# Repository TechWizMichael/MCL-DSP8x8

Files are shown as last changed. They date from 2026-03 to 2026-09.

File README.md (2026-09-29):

# MCL-DSP8x8
## Description
Audio Signal Processor based on ESP32-S3 and ADAU1452.

## Goals
+ Eight channels of analog audio input and output
+ Compatibility with "12V" automotive systems
+ Remote control through ESP32
+ download and upload of settings to restore after flashing new firmware

## Current State of Firmware
+ Bit of a mess. It's been changing as I've been messing with testing.
+ USB programming of ESP32 is functional.
+ ESP32 successfully programs ADAU1452 and AK4619VN.
+ Bluetooth functionality was briefly tested, with a generic BLE app on android controlling output gain.
+ Recommended to edit SigmaStudio project for own needs before programming.

## Current state of hardware
### V0.7 PCB (latest complete version)
- On paper, everything works. The ESP32-S3 may need to be flashed using UART pins for the first time, but it is otherwise functional.
- In practice, there are many issues that make it problematic for use with actual audio systems.
- View issues tab for current issues and progress/solutions

### v0.8 (In Progress)
- Goal to address many of the issues seen in v0.7.
- The primary issue is the noise in the analog signal, which is addressed by a second 3.3V rail for analog components.
- This means the main board has a maximum input and output of around +2.2dBu.
- There is also additional options for input connectors, but they must be added separately.
- The following connectors have complete v1 designs:
  - Stereo XLR
  - Stereo RCA
  - Eight-channel RCA
- Current designs for input boards passively attenuate signal -20dB, so a maximum input signal of +22dBu is acceptable.
- Maximum output is still around +2.2 dBu.
- If the maximum input signal will be under +2.2 dBu, the output boards can be used as input boards.
  - This is because they are direct connections to the main board.

#### v0.8 To-do:
- [x] New analog rail
- [x] Reset IC for ESP32
- [x] Upgrade buttons
- [x] Upgrade/Replace audio connectors
- [x] swap I2S connections for AK4619VN
- [x] \(optional) Ability to power from USB 5V rail
- [x] Update output gain stage
- [x] Add Schottky diode(s) for power input
- [x] Upgrade capacitors on input
- [x] add capacitors on power rails of opamps
- [x] ESP32 controls PDN of AK4619VN
- [x] Updated layout of main board
- [x] Connector boards
- [ ] Validation of assembled design

### Preview of v0.8 from JLCPCB


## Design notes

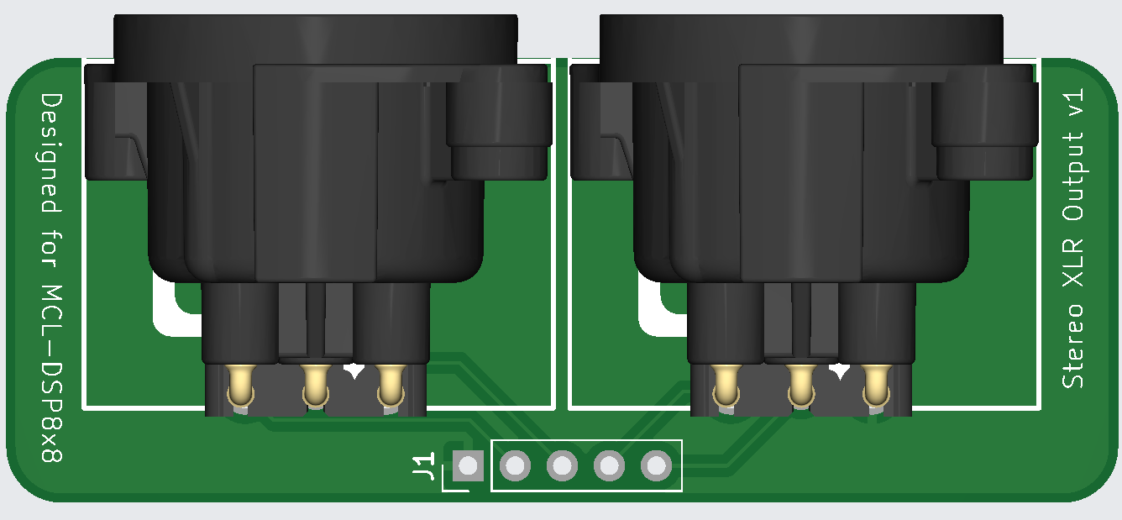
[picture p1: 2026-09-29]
PCB/MCL-DSP8x8_OUTPUT_XLR/production/Stereo XLR Output V1.png

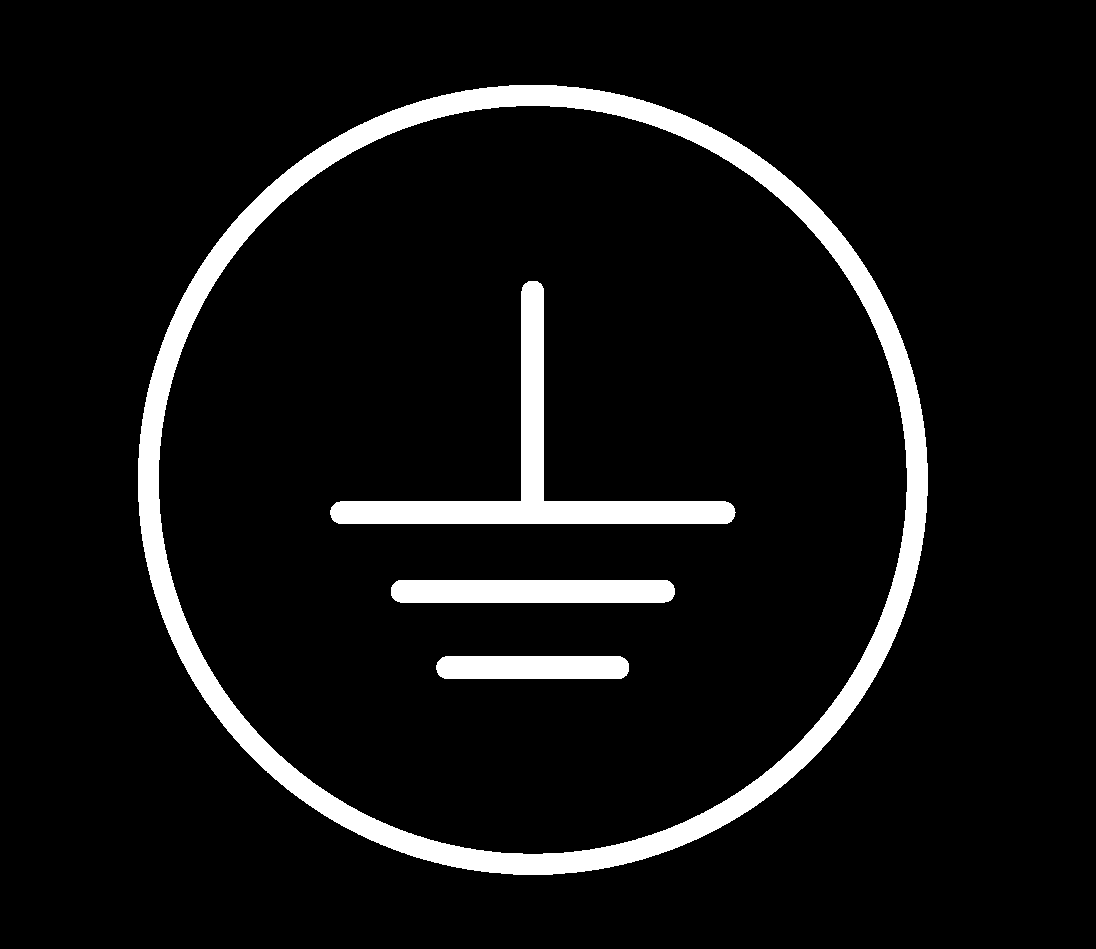
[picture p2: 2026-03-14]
PCB/DIYDSPv0.6/Silkscreen Ground Symbol.png

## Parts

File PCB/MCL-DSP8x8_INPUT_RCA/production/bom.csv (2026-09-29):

Designator | Footprint | Quantity | Value | LCSC Part #
CN1 | XDJK-0271-1650 | 1 | ~ | C7527522
R1, R3 | 0805 | 2 | 82k | C22356755
R2, R4, R6, R8 | 0805 | 4 | 10k | C3152175

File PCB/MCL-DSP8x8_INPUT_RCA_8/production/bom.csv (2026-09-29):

Designator | Footprint | Quantity | Value | LCSC Part #
CN1, CN2, CN3, CN4 | XDJK-0271-1650 | 4 | ~ | C7527522
R1, R13, R15, R17, R19, R3, R5, R7 | 0805 | 8 | 82k | C22356755
R10, R11, R12, R14, R16, R18, R2, R20, R21, R22, R23, R24, R4, R6, R8, R9 | 0805 | 16 | 10k | C3152175

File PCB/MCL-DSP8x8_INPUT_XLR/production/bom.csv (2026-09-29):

Designator | Footprint | Quantity | Value | LCSC Part #
PS1, PS2 | NC3FAAH1 | 2 | ~ | C368464
R1, R3, R5, R7 | 0805 | 4 | 82k | C22356755
R2, R4, R6, R8 | 0805 | 4 | 10k | C3152175

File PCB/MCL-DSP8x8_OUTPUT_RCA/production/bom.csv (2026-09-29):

Designator | Footprint | Quantity | Value | LCSC Part #
CN1 | XDJK-0271-1650 | 1 | ~ | C7527522
R6, R8 | 0805 | 2 | 10k | C3152175

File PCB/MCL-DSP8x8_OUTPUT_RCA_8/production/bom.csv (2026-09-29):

Designator | Footprint | Quantity | Value | LCSC Part #
CN1, CN2, CN3, CN4 | XDJK-0271-1650 | 4 | ~ | C7527522
R1, R2, R3, R4, R5, R6, R7, R8 | 0805 | 8 | 10k | C3152175

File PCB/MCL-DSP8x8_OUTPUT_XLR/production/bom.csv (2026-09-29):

Designator | Footprint | Quantity | Value | LCSC Part #
PS1 | NC3MAAH-0 | 1 | ~ | C368531
PS2 | NC3MAAH-0 | 1 | ~

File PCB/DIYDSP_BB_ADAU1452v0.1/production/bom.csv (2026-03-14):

Designator | Footprint | Quantity | Value | LCSC Part #
C1, C10, C11, C13, C17, C18, C21, C30, C32, C5, C7, C9 | 0805 | 12 | 100n | C28233
C12, C14, C16, C20 | 0805 | 4 | 10n | C1710
C15, C19, C22, C23 | 0805 | 4 | 1u | C28323
C2, C31, C33, C6, C8 | 0805 | 5 | 10u | C15850
C24, C25 | 0805 | 2 | 22p | C1804
C26 | 0805 | 1 | 4.7n | C1744
C27 | 0805 | 1 | 47p | C14857
C3 | 0805 | 1 | 1n | C46653
C4 | 0805 | 1 | 100p | C1790
D1 | 0805 | 1 | LED | C84256
R1, R5 | 0805 | 2 | 2.2k | C17520
R2, R3 | 0805 | 2 | 100 | C17408
R4 | 0805 | 1 | 1k | C17513
U1 | ADAU1452WBCPZ-RL | 1 | ADAU1452 | C462188
U2 | AMS1117-1.2 | 1 | AMS1117-1.2 | C2992568
Y1 | Crystal_SMD_5032-2Pin_5.0x3.2mm | 1 | 12.288M | C20624119

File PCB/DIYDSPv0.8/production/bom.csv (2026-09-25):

Designator | Footprint | Quantity | Value | LCSC Part #
C1, C101, C102, C108, C109, C112, C113, C13, C18, C20, C21, C25, C26, C28, C3, C42, C44, C58, C59, C64, C65, C76, C77, C84, C85, C96, C97 | 0603 | 27 | 10u | C96446
C10, C2, C4, C9 | 0402 | 4 | 2.2u | C12530
C100, C107, C68, C83 | RVT1V221M0810 | 4 | 220uF | C18221522
C103, C104, C110, C111, C50, C61, C78, C95 | 0805 | 8 | 22u | C45783
C105, C106, C11, C114, C115, C116, C12, C14, C15, C19, C22, C23, C24, C27, C33, C36, C38, C39, C40, C41, C47, C48, C49, C5, C51, C52, C53, C6, C60, C62, C63, C66, C67, C73, C74, C75, C86, C87, C88, C89, C94, C98, C99 | 0402 | 43 | 100n | C307331
C16, C17, C34, C35 | 0402 | 4 | 10n | C15195
C29 | 0402 | 1 | 4.7n | C1538
C30, C31, C45, C46, C54, C55, C56, C57, C69, C70, C71, C72, C79, C80, C81, C82, C90, C91, C92, C93 | 0402 | 20 | 1u | C52923
C32 | 0402 | 1 | 1n | C1523
C37 | 0402 | 1 | 100p | C1546
C43 | 0402 | 1 | 47p | C1567
C7, C8 | 0402 | 2 | 22p | C1555
CN1 | MX126-5.0-02P-GN01-Cu-S-A | 1 | ~ | C5188434
D1, D2, D7, D8 | 0805 | 4 | LED | C84256
D3, D4, D5 | CUS08F30,H3F | 3 | ~ | C150183
D6 | SMF20CA | 1 | ~ | C42371747
R1, R10, R11, R14, R19, R2, R20, R25, R3, R4, R5, R6, R7, R74, R8, R81, R9 | 0805 | 17 | 100 | C17408
R12, R13, R21, R26, R27 | 0402 | 5 | 10k | C25744
R15, R18, R28, R29, R44, R45, R56, R57, R70, R71 | 0402 | 10 | 1k | C11702
R16, R17 | 0402 | 2 | 2.2k | C25879
R22, R30, R31, R32, R33, R34, R35, R36, R37, R38, R39, R40, R41, R42, R43, R46, R47, R48, R49, R50, R51, R52, R53, R54, R55, R58, R59, R60, R61, R62, R63, R64, R65, R66, R67, R68, R69, R72, R73, R75, R76, R77, R78, R79, R80 | 0402 | 45 | 100k | C25741
R23, R24 | 0402 | 2 | 5.1k | C25905
SW1, SW2, SW3 | TS110916043 | 3 | ~ | C22375348
U1 | ADAU1452WBCPZ-RL | 1 | ADAU1452 | C462188
U10, U11, U12, U13, U14, U15, U16, U17, U18, U19, U20, U21, U22, U24, U25, U8, U9 | TLV9062IDR | 17 | ~ | C398355
U2, U3 | AK4619VN | 2 | ~ | C3034747
U23, U26 | K7803-1000_C50396471 | 2 | ~
U4 | AMS1117-1.2 | 1 | AMS1117-1.2 | C2992568
U5 | ESP32-S3-WROOM-1U-N8 | 1 | ~ | C3013946
U6 | ADM811TARTZ-REEL7 | 1 | ~ | C462205
U7 | GT-USB-7010ASV | 1 | ~ | C2988369
X1 | S47SMD12.288M20PF20R30B3 | 1 | 12.288MHz | C5346044

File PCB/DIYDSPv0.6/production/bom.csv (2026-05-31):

Designator | Footprint | Quantity | Value | LCSC Part #
C1, C14, C19, C24, C25, C27, C3, C31, C32, C34, C51 | 0603 | 11 | 10u | C96446
C10, C11, C12, C55, C7 | 0805 | 5 | 22u | C45783
C13, C17, C18, C20, C21, C26, C28, C29, C30, C33, C39, C43, C44, C45, C46, C48, C5, C52, C53, C54, C56, C57, C6 | 0402 | 23 | 100n | C307331
C15, C16, C2, C4 | 0402 | 4 | 2.2u | C12530
C22, C23, C40, C41 | 0402 | 4 | 10n | C15195
C35 | 0402 | 1 | 4.7n | C1538
C36, C37, C49, C50, C58, C59, C60, C61, C62, C63, C64, C65, C66, C67, C68, C69, C70, C71, C72, C73, C74, C75, C76, C77, C78, C79, C80, C81, C82, C83, C84, C85, C86, C87, C88, C89 | 0402 | 36 | 1u | C52923
C38 | 0402 | 1 | 1n | C1523
C42 | 0402 | 1 | 100p | C1546
C47 | 0402 | 1 | 47p | C1567
C8, C9 | 0402 | 2 | 22p | C1555
CN1 | MX126-5.0-02P-GN01-Cu-S-A | 1 | ~ | C5188434
D1 | SMF20CA | 1 | ~ | C42371747
D2, D3, D4 | 0805 | 3 | LED | C84256
R1, R10, R11, R17, R18, R19, R2, R23, R24, R3, R4, R5, R6, R7, R8, R9 | 0805 | 16 | 100 | C17408
R12, R13, R25, R26, R27, R76 | 0402 | 6 | 10k | C25744
R14, R36, R37, R38, R39, R40, R41, R42, R43, R44, R45, R46, R47, R48, R49, R50, R51, R60, R61, R62, R63, R64, R65, R66, R67, R68, R69, R70, R71, R72, R73, R74, R75 | 0402 | 33 | 100k | C25741
R15, R16 | 0402 | 2 | 2.2k | C25879
R20 | 0402 | 1 | 1k | C11702
R21, R22 | 0402 | 2 | 5.1k | C25905
R28, R29, R30, R31, R32, R33, R34, R35, R52, R53, R54, R55, R56, R57, R58, R59 | 0603 | 16 | 220k | C22961
U1 | ADAU1452WBCPZ-RL | 1 | ADAU1452 | C462188
U10 | GT-USB-7010ASV | 1 | ~ | C2988369
U11, U12, U13, U14, U15, U16, U8, U9 | PJ-320D | 8 | ~ | C22459515
U17 | ESP32-S3-WROOM-1U-N8 | 1 | ~ | C3013946
U18, U19, U7 | YTS1C0033BBG01 | 3 | ~ | C5188566
U2, U3 | AK4619VN | 2 | ~ | C3034747
U20, U21, U22, U23 | LM324DT | 4 | ~ | C71035
U4 | K7803M-1000R3 | 1 | ~ | C22749779
U5 | AMS1117-1.2 | 1 | AMS1117-1.2 | C2992568
U6 | ADM811TARTZ-REEL7 | 1 | ~ | C462205
X1 | S47SMD12.288M20PF20R30B3 | 1 | 12.288MHz | C5346044

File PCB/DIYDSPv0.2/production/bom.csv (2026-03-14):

Designator | Footprint | Quantity | Value | LCSC Part #
C1, C15, C2, C27, C28, C29, C48, C5, C52, C53, C54, C55, C56, C57, C58, C59, C6, C8, C9 | 0805 | 19 | 10u | C15850
C10, C11, C33, C50, C7 | 0805 | 5 | 22u | C45783
C12, C13, C14, C16, C17, C18, C19, C20, C21, C24, C25, C26, C37, C41, C42, C43, C44, C49, C51 | 0603 | 19 | 100n | C14663
C22, C23, C38, C39 | 0402 | 4 | 10n | C15195
C3, C4 | 0402 | 2 | 22p | C1555
C30 | 0402 | 1 | 4.7n | C1538
C31, C32, C46, C47, C60, C61, C62, C63, C64, C65, C66, C67, C68, C69, C70, C71, C72, C73, C74, C75, C76, C77, C78, C79, C80, C81, C82, C83, C84, C85, C86, C87, C88, C89, C90, C91 | 0402 | 36 | 1u | C52923
C34 | 0402 | 1 | 1n | C1523
C35, C36 | 0805 | 2 | 2.2u | C377773
C40 | 0402 | 1 | 100p | C1546
C45 | 0402 | 1 | 47p | C1567
D1 | SMF20CA | 1 | ~ | C42371747
D2, D3, D4 | 0805 | 3 | LED | C84256
R1, R4, R5, R6 | 1206 | 4 | 100 | C17901
R10, R100, R101, R102, R103, R104, R105, R106, R107, R108, R109, R11, R110, R111, R112, R113, R114, R115, R12, R13, R14, R15, R20, R21, R22, R23, R24, R25, R26, R27, R32, R33, R34, R35, R44, R45, R46, R47, R48, R49, R50, R51, R52, R53, R54, R55, R56, R57, R58, R59, R60, R61, R62, R63, R64, R65, R66, R67, R68, R69, R70, R71, R72, R73, R74, R75, R84, R85, R86, R87, R88, R89, R90, R91, R92, R93, R94, R95, R96, R97, R98, R99 | 1206 | 82 | 10k | C17902
R16, R17, R18, R19, R28, R29, R30, R31, R36, R37, R38, R39, R40, R41, R42, R43, R76, R77, R78, R79, R80, R81, R82, R83 | 0805 | 24 | 22k | C17560
R2, R3 | 0603 | 2 | 2.2k | C4190
R7, R8 | 0603 | 2 | 5.1k | C23186
R9 | 0402 | 1 | 1k | C11702
U1, U5 | AK4619VN | 2 | ~ | C3034747
U10, U12, U13, U14, U15, U16, U17, U18, U19, U7, U8, U9 | TS912IDT | 12 | ~ | C73655
U11 | ESP32-S3-WROOM-1 | 1 | ~
U2 | ADAU1452WBCPZ-RL | 1 | ADAU1452 | C462188
U3 | K7803M-1000R3 | 1 | ~ | C22749779
U4 | AMS1117-1.2 | 1 | AMS1117-1.2 | C2992568
U6 | GT-USB-7010ASV | 1 | ~ | C2988369
Y1 | Crystal_SMD_5032-2Pin_5.0x3.2mm | 1 | 12.288M | C20624119

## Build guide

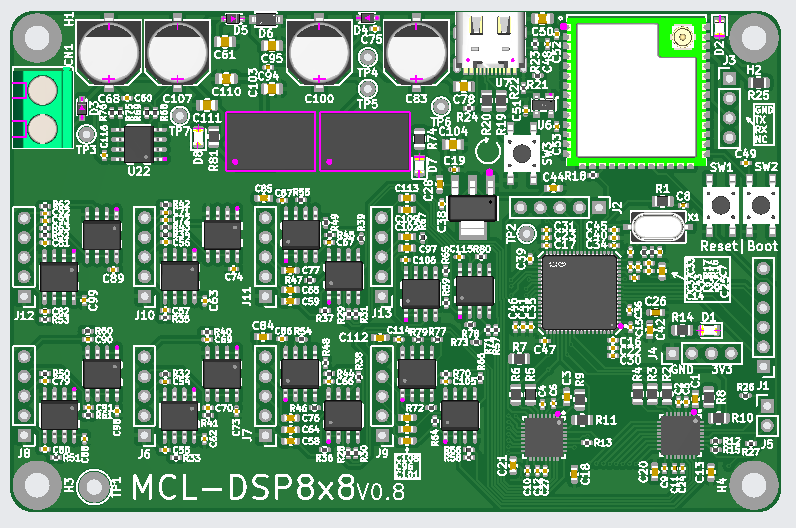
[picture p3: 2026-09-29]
PCB/DIYDSPv0.8/production/MCL-DSP8x8v0.8 Assembled Preview.png

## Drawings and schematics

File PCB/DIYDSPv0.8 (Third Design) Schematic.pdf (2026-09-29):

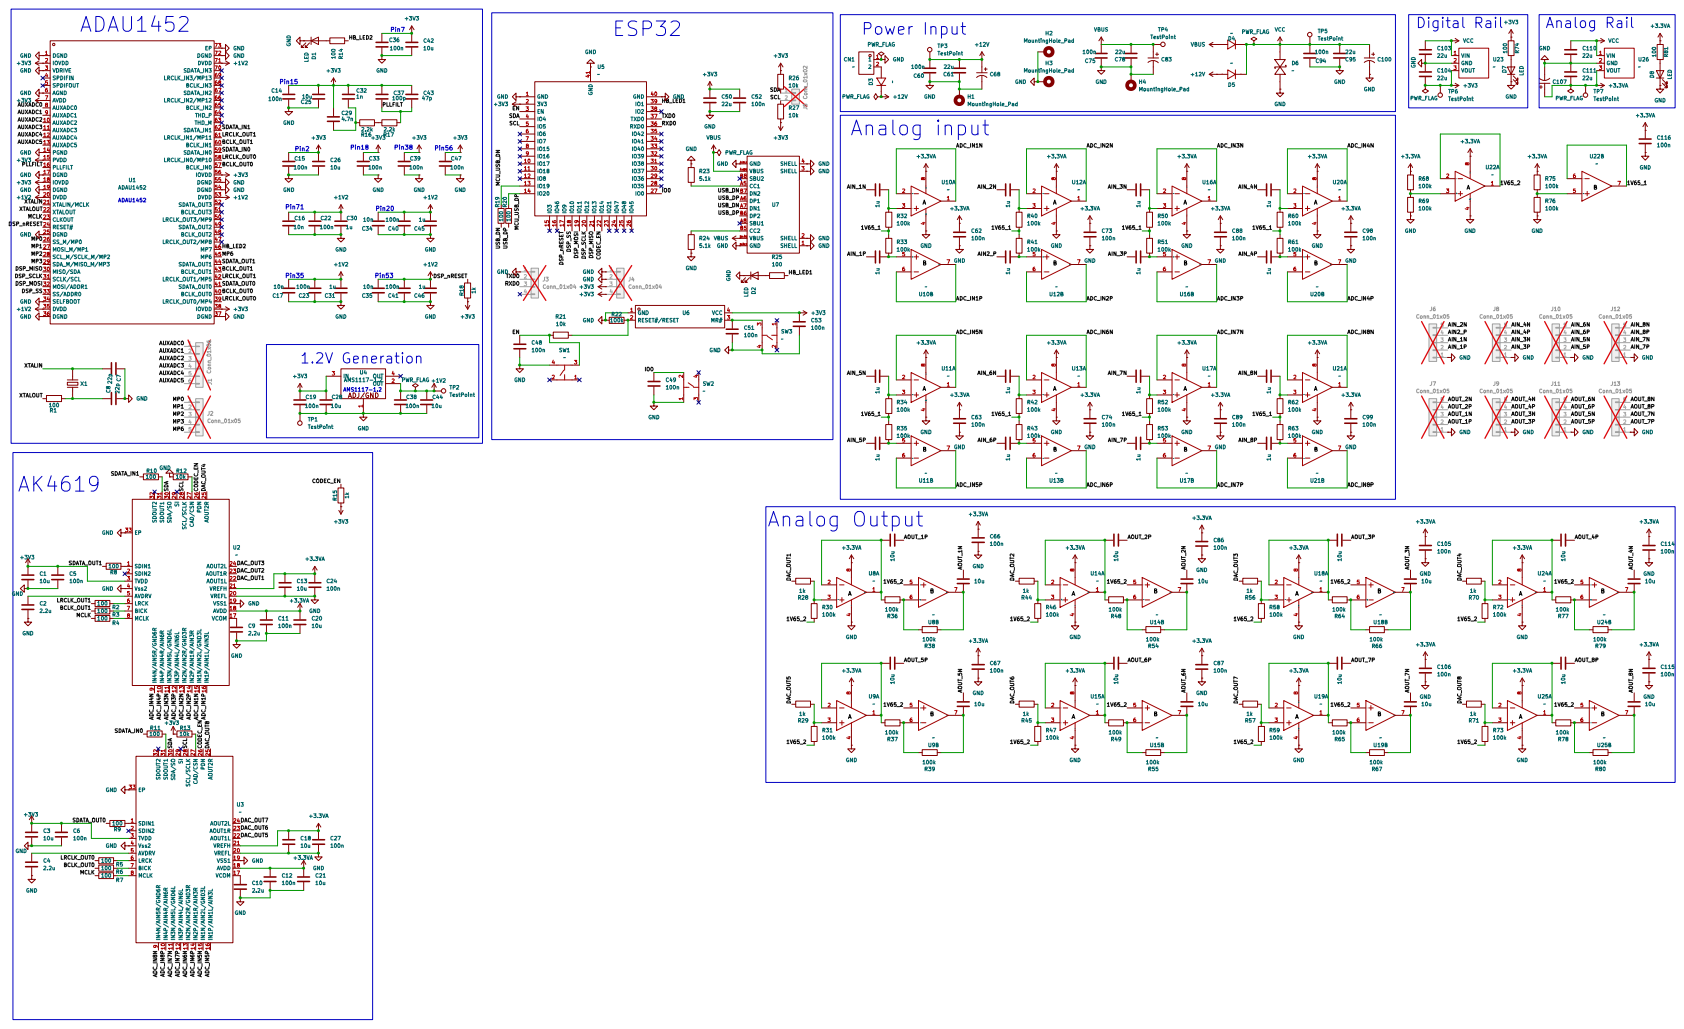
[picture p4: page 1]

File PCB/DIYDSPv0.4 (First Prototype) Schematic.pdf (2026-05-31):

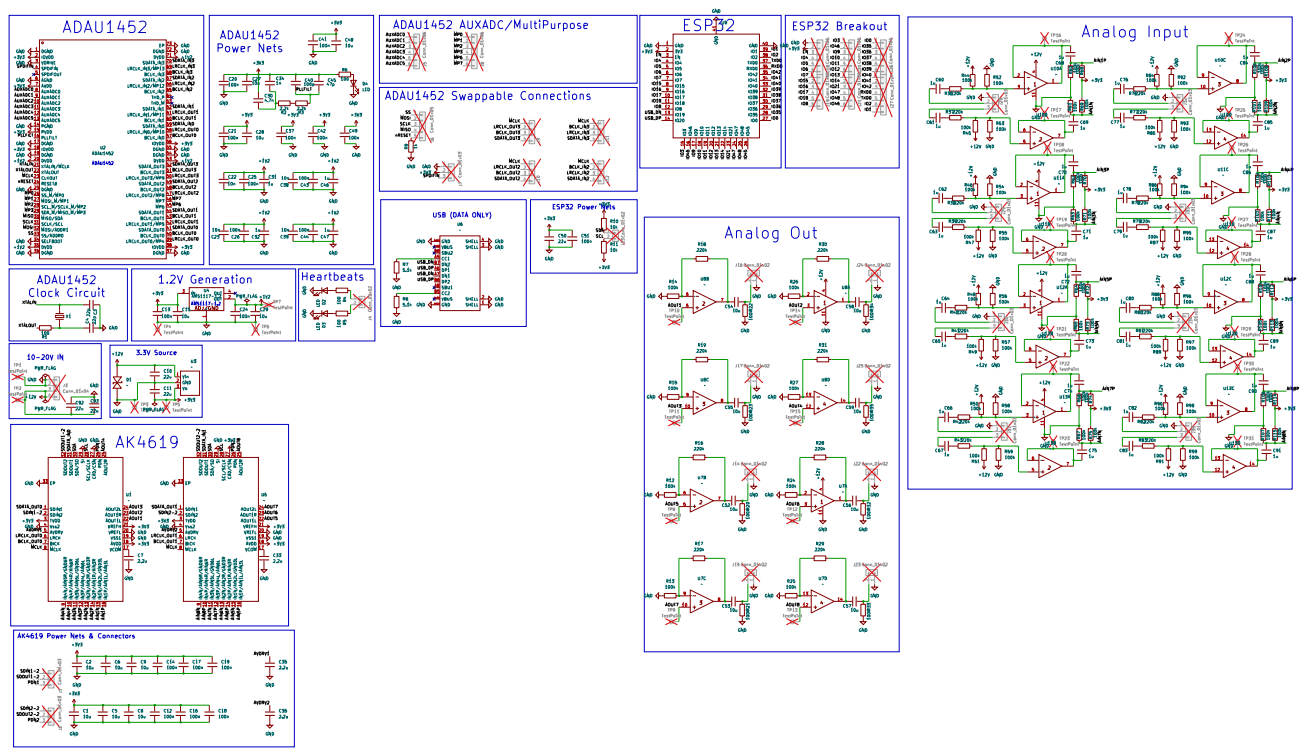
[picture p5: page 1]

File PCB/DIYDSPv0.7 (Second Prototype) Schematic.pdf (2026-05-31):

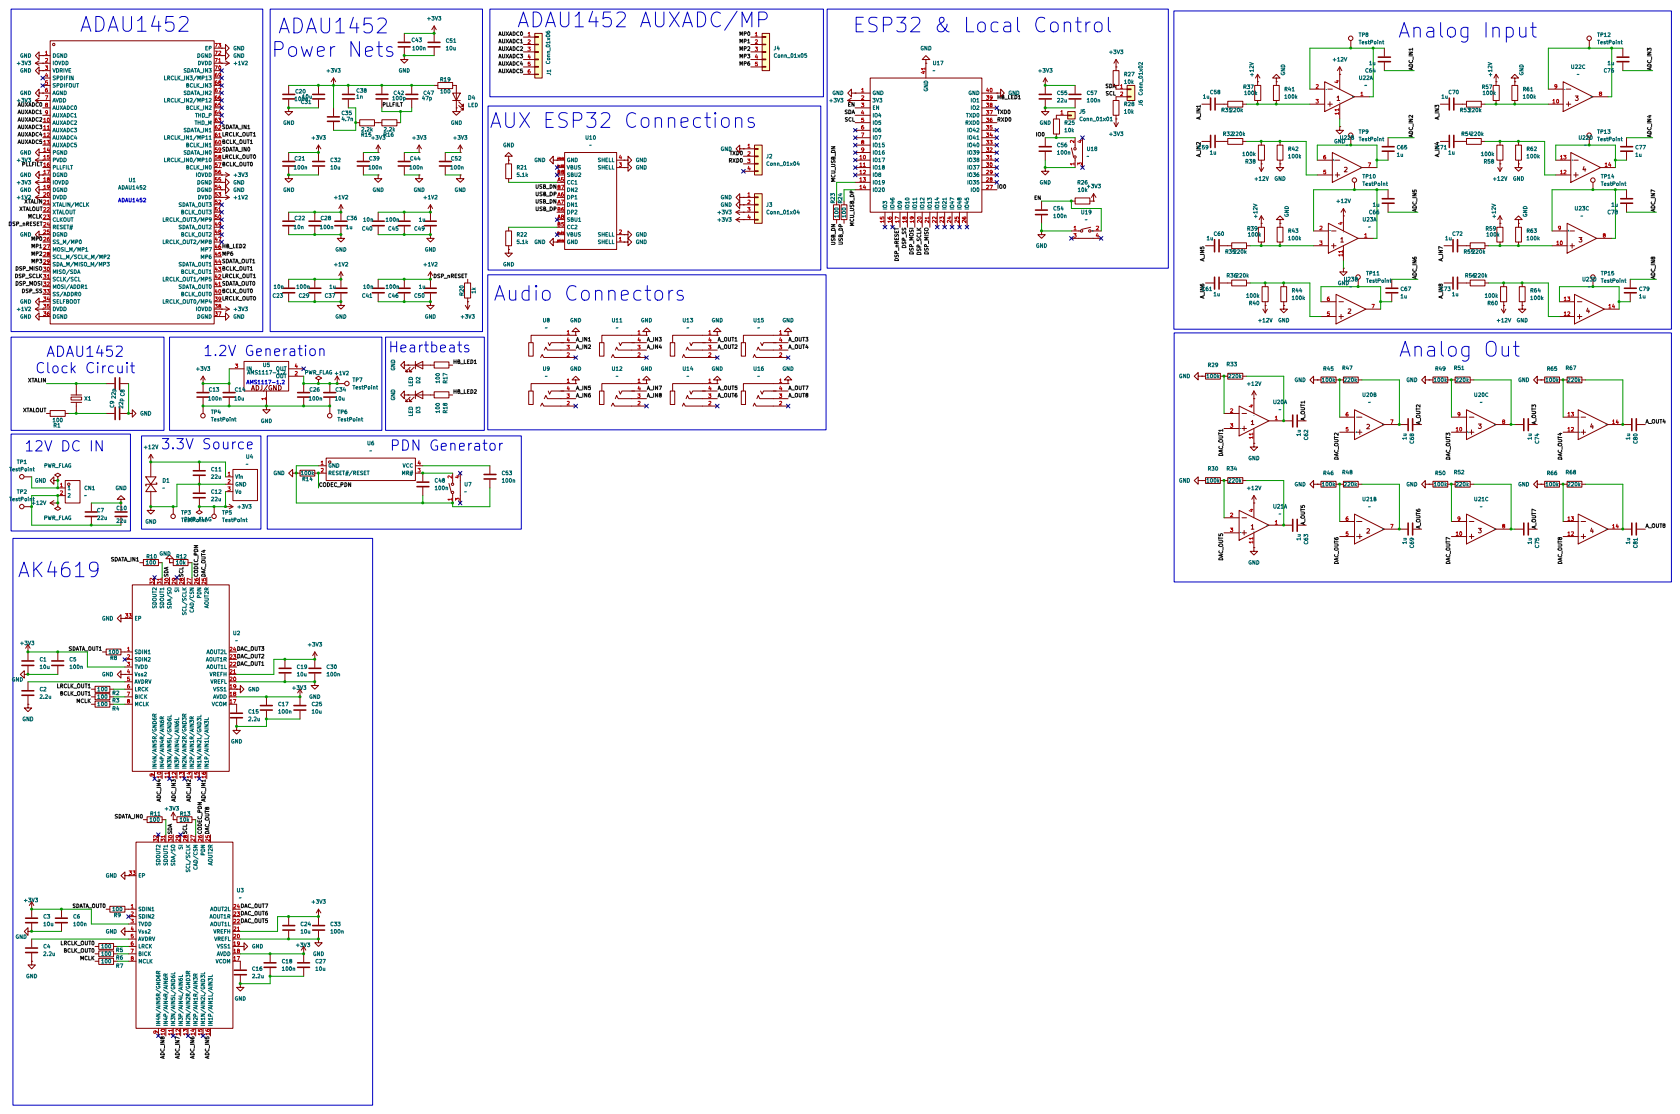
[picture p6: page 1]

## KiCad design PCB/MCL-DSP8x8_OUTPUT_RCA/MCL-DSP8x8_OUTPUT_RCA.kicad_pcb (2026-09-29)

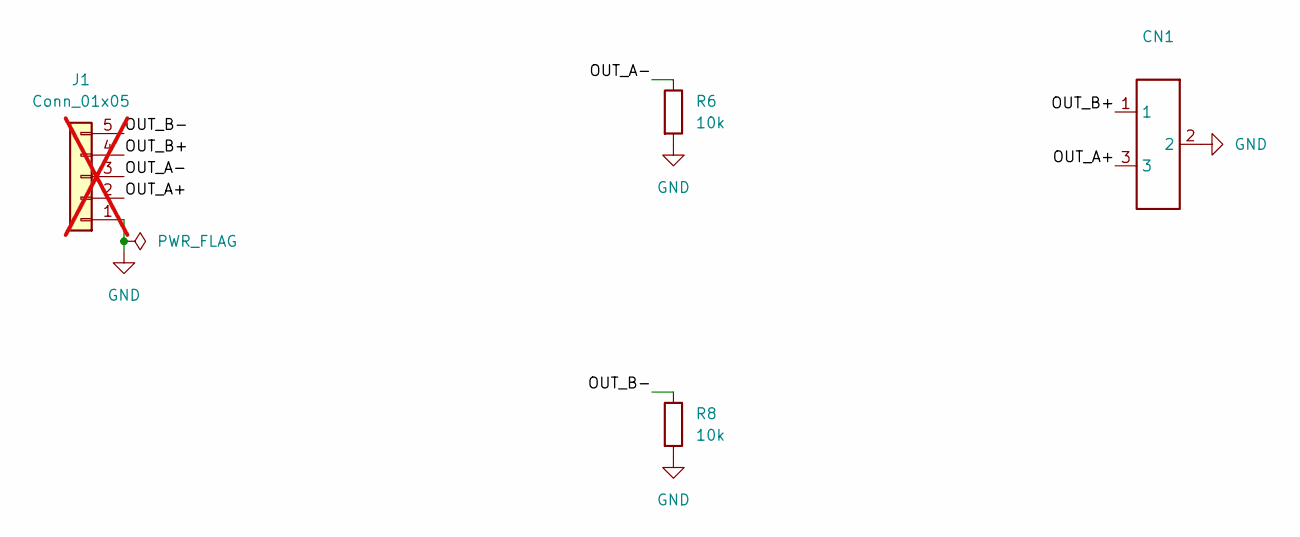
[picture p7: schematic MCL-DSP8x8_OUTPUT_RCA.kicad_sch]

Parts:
CN1: XDJK-0271-1650; Manufacturer Part XDJK-0271-1650; LCSC Part Name 双层莲花座
J1: Conn_01x05; PinHeader_1x05_P2.54mm_Vertical; not fitted
R6, R8: 10k; R_0805_2012Metric_Pad1.20x1.40mm_HandSolder; LCSC Part # C3152175

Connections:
/OUT_A+: CN1.3, J1.2
/OUT_A-: J1.3, R6.1
/OUT_B+: CN1.1, J1.4
/OUT_B-: J1.5, R8.1
GND: CN1.2, J1.1, R6.2, R8.2

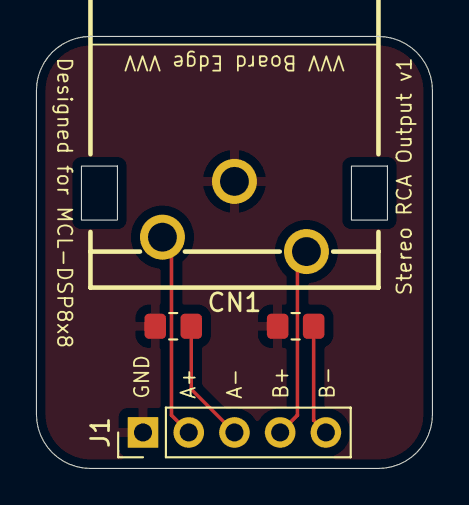
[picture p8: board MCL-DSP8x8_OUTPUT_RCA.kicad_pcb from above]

Board: 2 copper layers, 22.0 x 24.0 mm, 4 parts (0 on the bottom side), 5 nets.

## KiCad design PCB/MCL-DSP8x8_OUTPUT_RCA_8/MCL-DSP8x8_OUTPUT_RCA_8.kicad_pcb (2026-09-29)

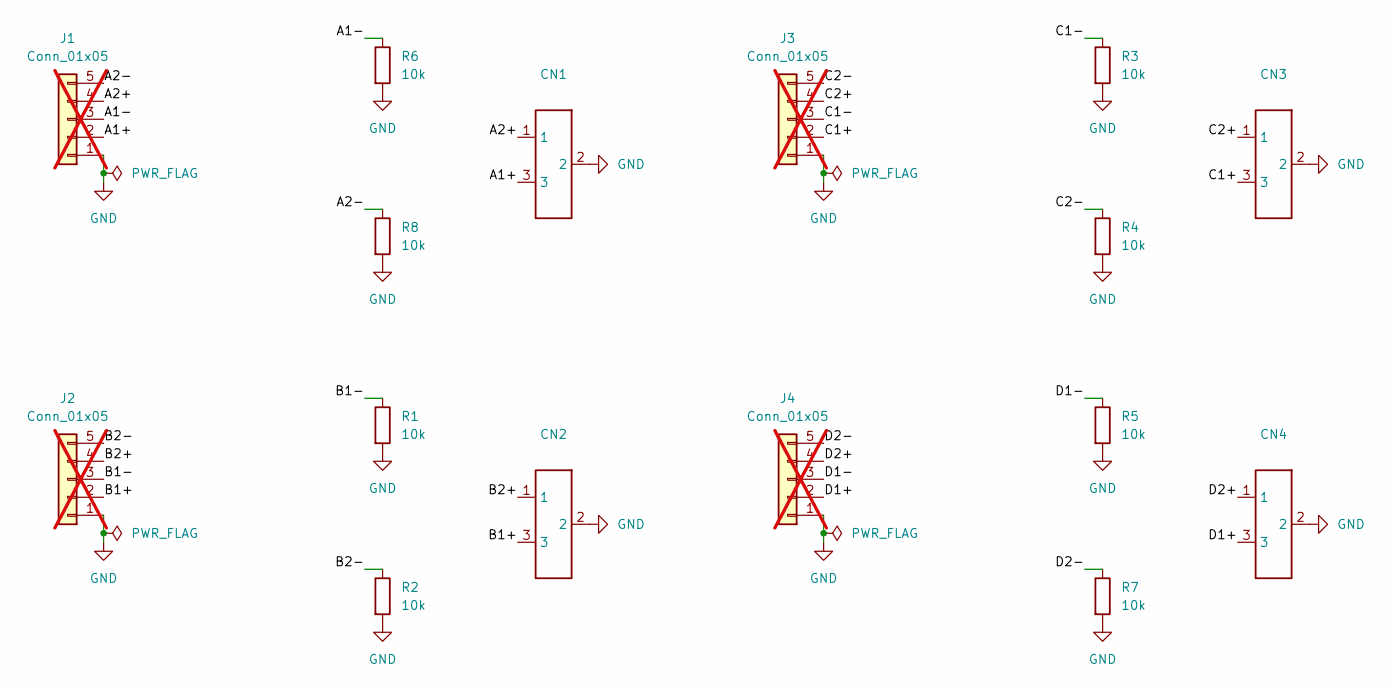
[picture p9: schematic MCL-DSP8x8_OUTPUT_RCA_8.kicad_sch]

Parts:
CN1, CN2, CN3, CN4: XDJK-0271-1650; Manufacturer Part XDJK-0271-1650; LCSC Part Name 双层莲花座
J1, J2, J3, J4: Conn_01x05; PinHeader_1x05_P2.54mm_Vertical; not fitted
R1, R2, R3, R4, R5, R6, R7, R8: 10k; R_0805_2012Metric_Pad1.20x1.40mm_HandSolder; LCSC Part # C3152175

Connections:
/A1+: CN1.3, J1.2
/A1-: J1.3, R6.1
/A2+: CN1.1, J1.4
/A2-: J1.5, R8.1
/B1+: CN2.3, J2.2
/B1-: J2.3, R1.1
/B2+: CN2.1, J2.4
/B2-: J2.5, R2.1
/C1+: CN3.3, J3.2
/C1-: J3.3, R3.1
/C2+: CN3.1, J3.4
/C2-: J3.5, R4.1
/D1+: CN4.3, J4.2
/D1-: J4.3, R5.1
/D2+: CN4.1, J4.4
/D2-: J4.5, R7.1
GND: CN1.2, CN2.2, CN3.2, CN4.2, J1.1, J2.1, J3.1, J4.1, R1.2, R2.2, R3.2, R4.2, R5.2, R6.2, R7.2, R8.2

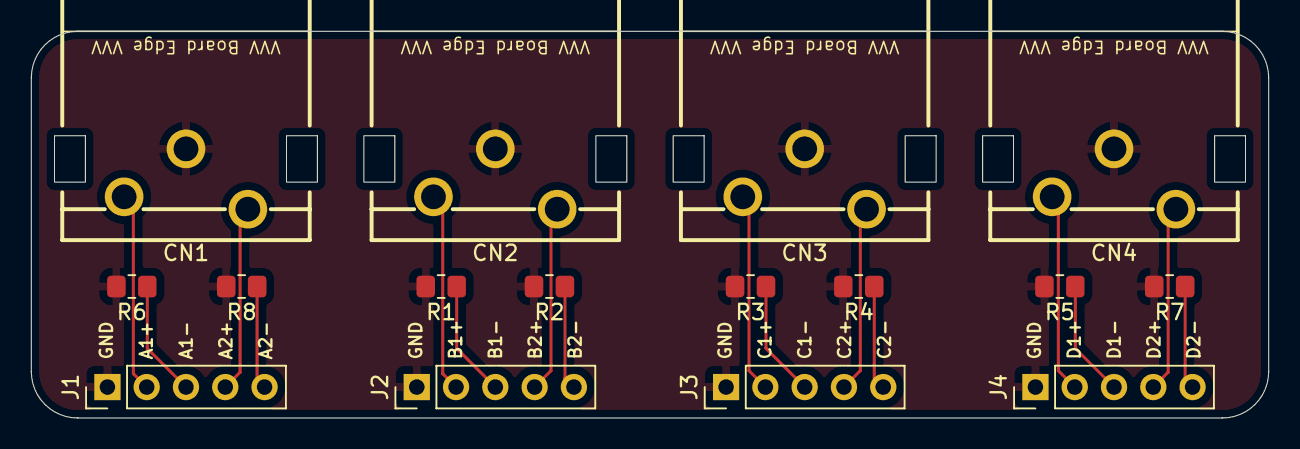
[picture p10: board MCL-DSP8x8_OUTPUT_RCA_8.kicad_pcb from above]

Board: 2 copper layers, 80.0 x 25.0 mm, 16 parts (0 on the bottom side), 17 nets.

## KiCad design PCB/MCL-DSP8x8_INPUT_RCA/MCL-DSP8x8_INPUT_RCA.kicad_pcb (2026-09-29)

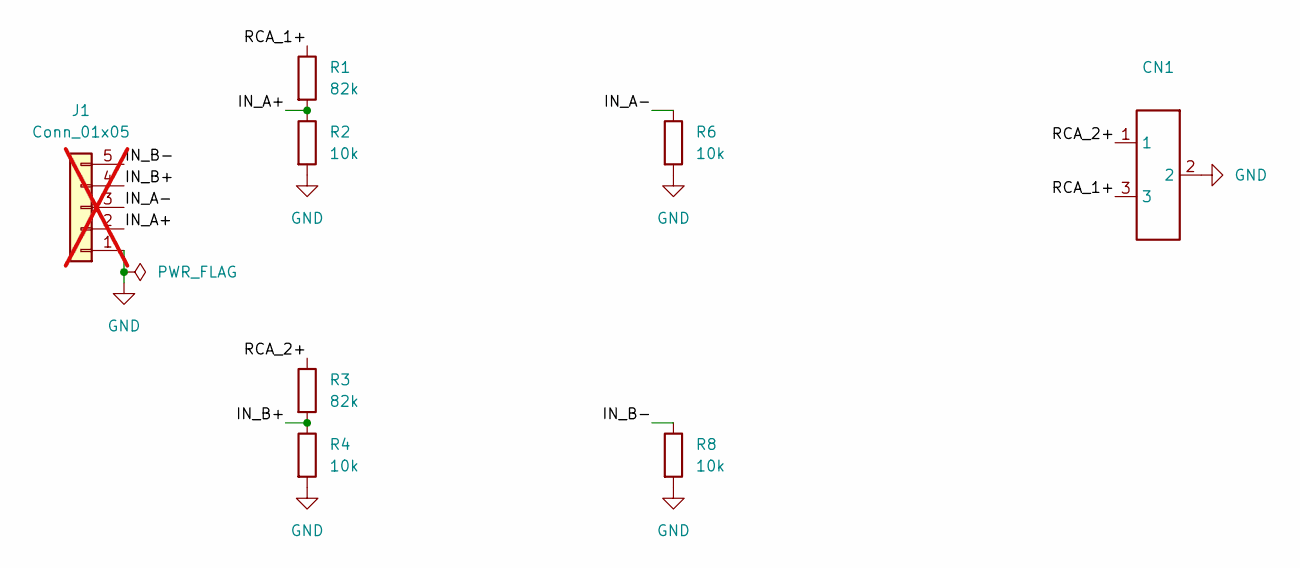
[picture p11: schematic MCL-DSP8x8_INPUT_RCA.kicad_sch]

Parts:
CN1: XDJK-0271-1650; Manufacturer Part XDJK-0271-1650; LCSC Part Name 双层莲花座
J1: Conn_01x05; PinHeader_1x05_P2.54mm_Vertical; not fitted
R1, R3: 82k; R_0805_2012Metric_Pad1.20x1.40mm_HandSolder; LCSC Part # C22356755
R2, R4, R6, R8: 10k; R_0805_2012Metric_Pad1.20x1.40mm_HandSolder; LCSC Part # C3152175

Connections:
/IN_A+: J1.2, R1.2, R2.1
/IN_A-: J1.3, R6.1
/IN_B+: J1.4, R3.2, R4.1
/IN_B-: J1.5, R8.1
/RCA_1+: CN1.3, R1.1
/RCA_2+: CN1.1, R3.1
GND: CN1.2, J1.1, R2.2, R4.2, R6.2, R8.2

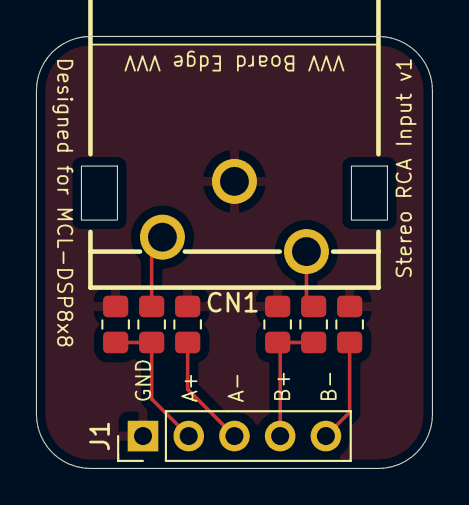
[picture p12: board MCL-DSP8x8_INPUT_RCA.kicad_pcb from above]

Board: 2 copper layers, 22.0 x 24.0 mm, 8 parts (0 on the bottom side), 7 nets.

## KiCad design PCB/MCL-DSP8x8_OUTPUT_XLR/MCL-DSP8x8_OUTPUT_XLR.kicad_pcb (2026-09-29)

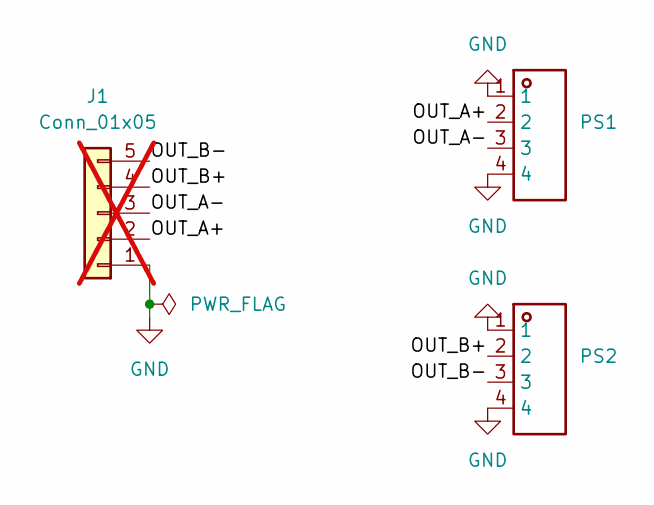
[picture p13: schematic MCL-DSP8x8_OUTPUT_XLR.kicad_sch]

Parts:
J1: Conn_01x05; PinHeader_1x05_P2.54mm_Vertical; not fitted
PS1, PS2: NC3MAAH-0; Manufacturer Part NC3MAAH-0; LCSC Part Name NC3MAAH-0

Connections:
/OUT_A+: J1.2, PS1.2
/OUT_A-: J1.3, PS1.3
/OUT_B+: J1.4, PS2.2
/OUT_B-: J1.5, PS2.3
GND: J1.1, PS1.1, PS1.4, PS2.1, PS2.4

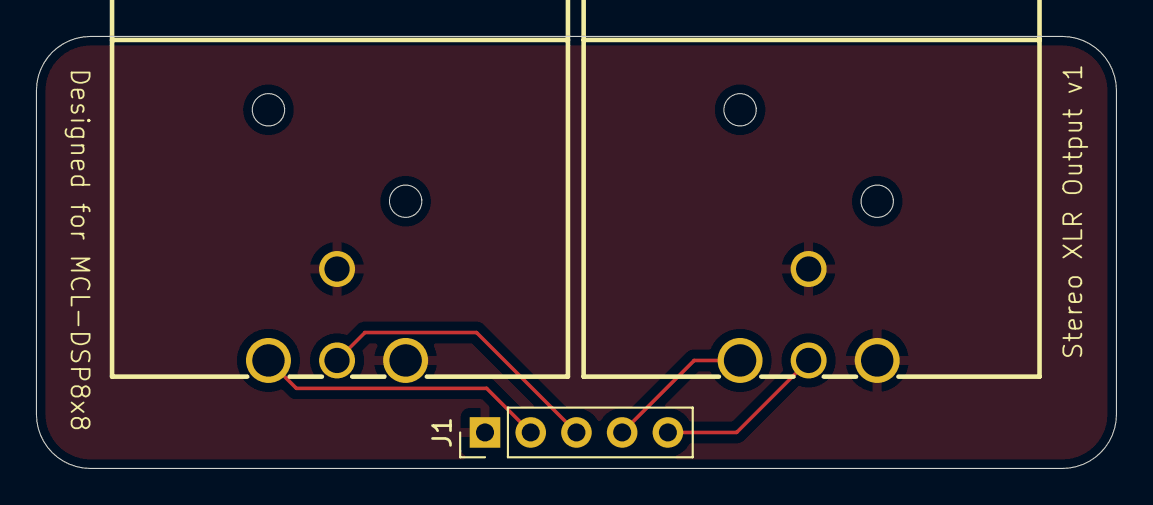
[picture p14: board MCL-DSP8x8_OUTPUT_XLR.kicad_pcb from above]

Board: 2 copper layers, 60.0 x 24.0 mm, 3 parts (0 on the bottom side), 5 nets.

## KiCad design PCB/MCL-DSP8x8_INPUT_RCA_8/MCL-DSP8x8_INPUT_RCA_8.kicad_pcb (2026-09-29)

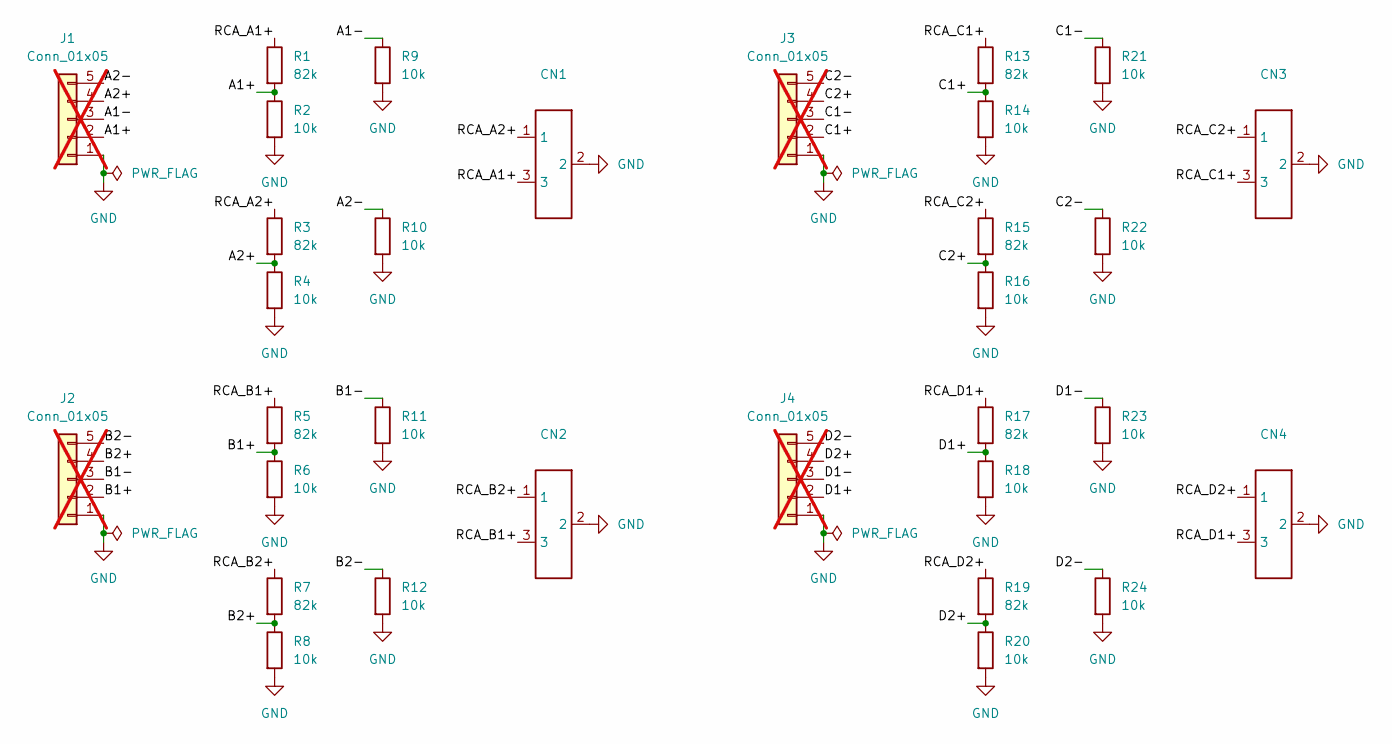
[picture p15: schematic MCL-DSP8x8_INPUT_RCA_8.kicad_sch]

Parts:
CN1, CN2, CN3, CN4: XDJK-0271-1650; Manufacturer Part XDJK-0271-1650; LCSC Part Name 双层莲花座
J1, J2, J3, J4: Conn_01x05; PinHeader_1x05_P2.54mm_Vertical; not fitted
R1, R3, R5, R7, R13, R15, R17, R19: 82k; R_0805_2012Metric_Pad1.20x1.40mm_HandSolder; LCSC Part # C22356755
R2, R4, R6, R8, R9, R10, R11, R12, R14, R16, R18, R20, R21, R22, R23, R24: 10k; R_0805_2012Metric_Pad1.20x1.40mm_HandSolder; LCSC Part # C3152175

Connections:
/A1+: J1.2, R1.2, R2.1
/A1-: J1.3, R9.1
/A2+: J1.4, R3.2, R4.1
/A2-: J1.5, R10.1
/B1+: J2.2, R5.2, R6.1
/B1-: J2.3, R11.1
/B2+: J2.4, R7.2, R8.1
/B2-: J2.5, R12.1
/C1+: J3.2, R13.2, R14.1
/C1-: J3.3, R21.1
/C2+: J3.4, R15.2, R16.1
/C2-: J3.5, R22.1
/D1+: J4.2, R17.2, R18.1
/D1-: J4.3, R23.1
/D2+: J4.4, R19.2, R20.1
/D2-: J4.5, R24.1
/RCA_A1+: CN1.3, R1.1
/RCA_A2+: CN1.1, R3.1
/RCA_B1+: CN2.3, R5.1
/RCA_B2+: CN2.1, R7.1
/RCA_C1+: CN3.3, R13.1
/RCA_C2+: CN3.1, R15.1
/RCA_D1+: CN4.3, R17.1
/RCA_D2+: CN4.1, R19.1
GND: CN1.2, CN2.2, CN3.2, CN4.2, J1.1, J2.1, J3.1, J4.1, R2.2, R4.2, R6.2, R8.2, R9.2, R10.2, R11.2, R12.2, R14.2, R16.2, R18.2, R20.2, R21.2, R22.2, R23.2, R24.2

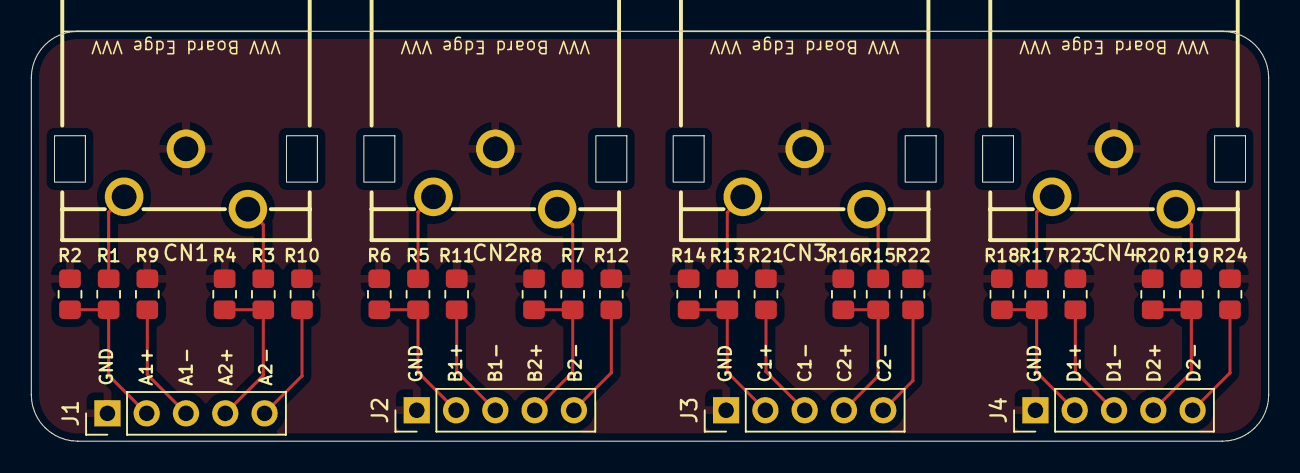
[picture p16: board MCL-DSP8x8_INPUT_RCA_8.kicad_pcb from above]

Board: 2 copper layers, 80.0 x 26.5 mm, 32 parts (0 on the bottom side), 25 nets.

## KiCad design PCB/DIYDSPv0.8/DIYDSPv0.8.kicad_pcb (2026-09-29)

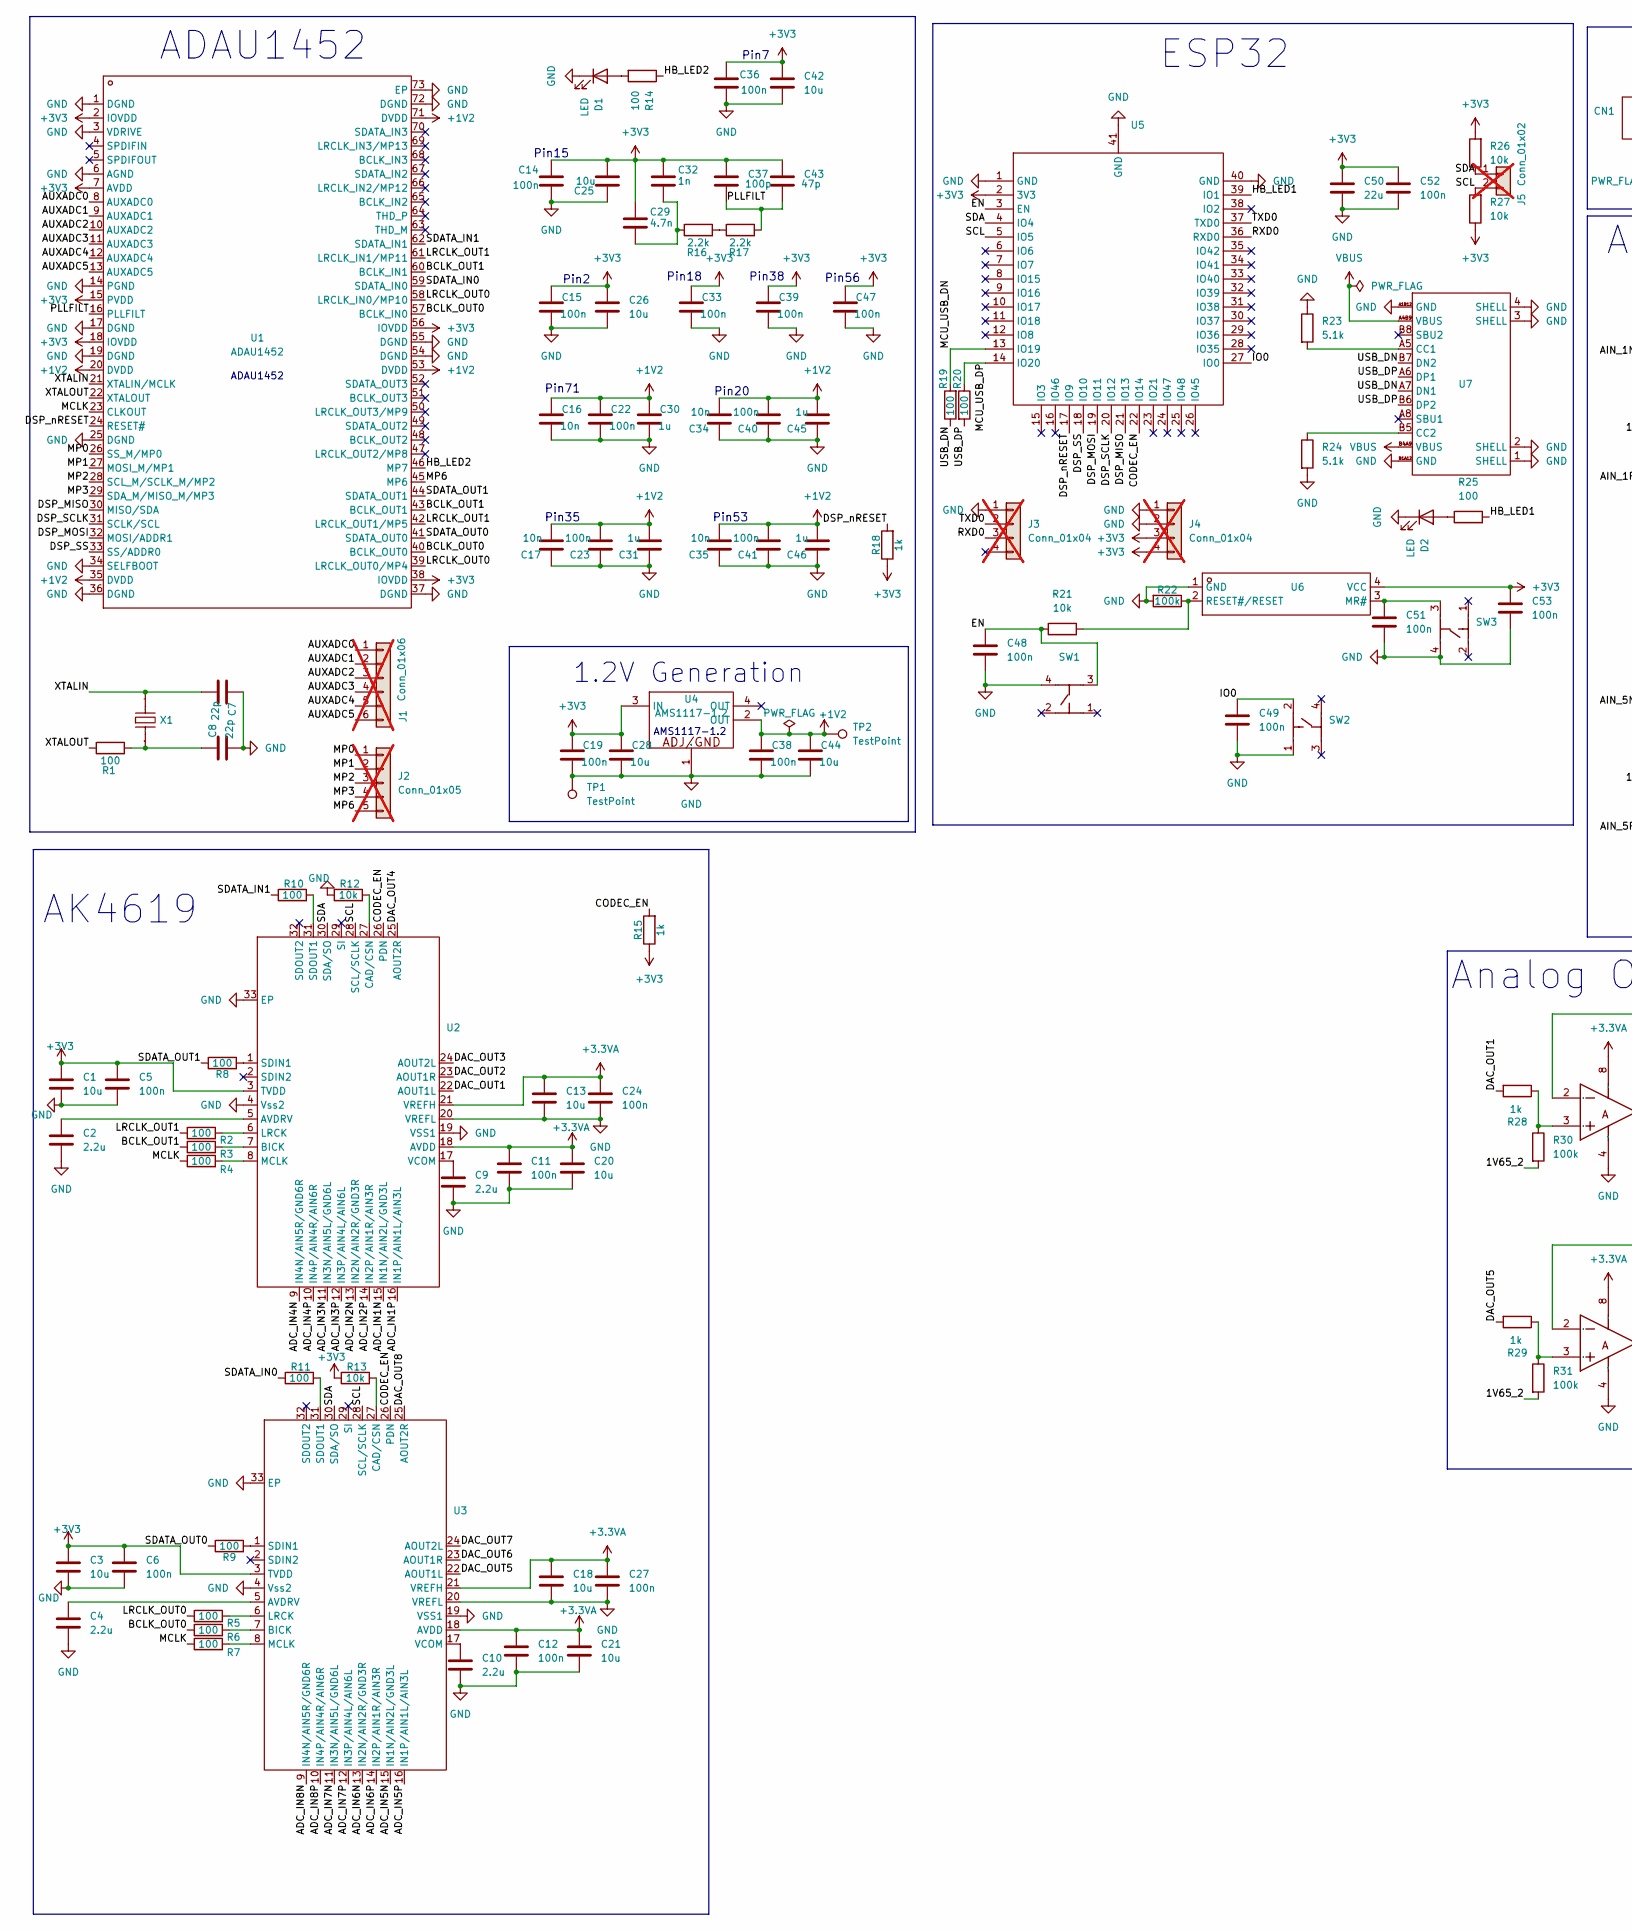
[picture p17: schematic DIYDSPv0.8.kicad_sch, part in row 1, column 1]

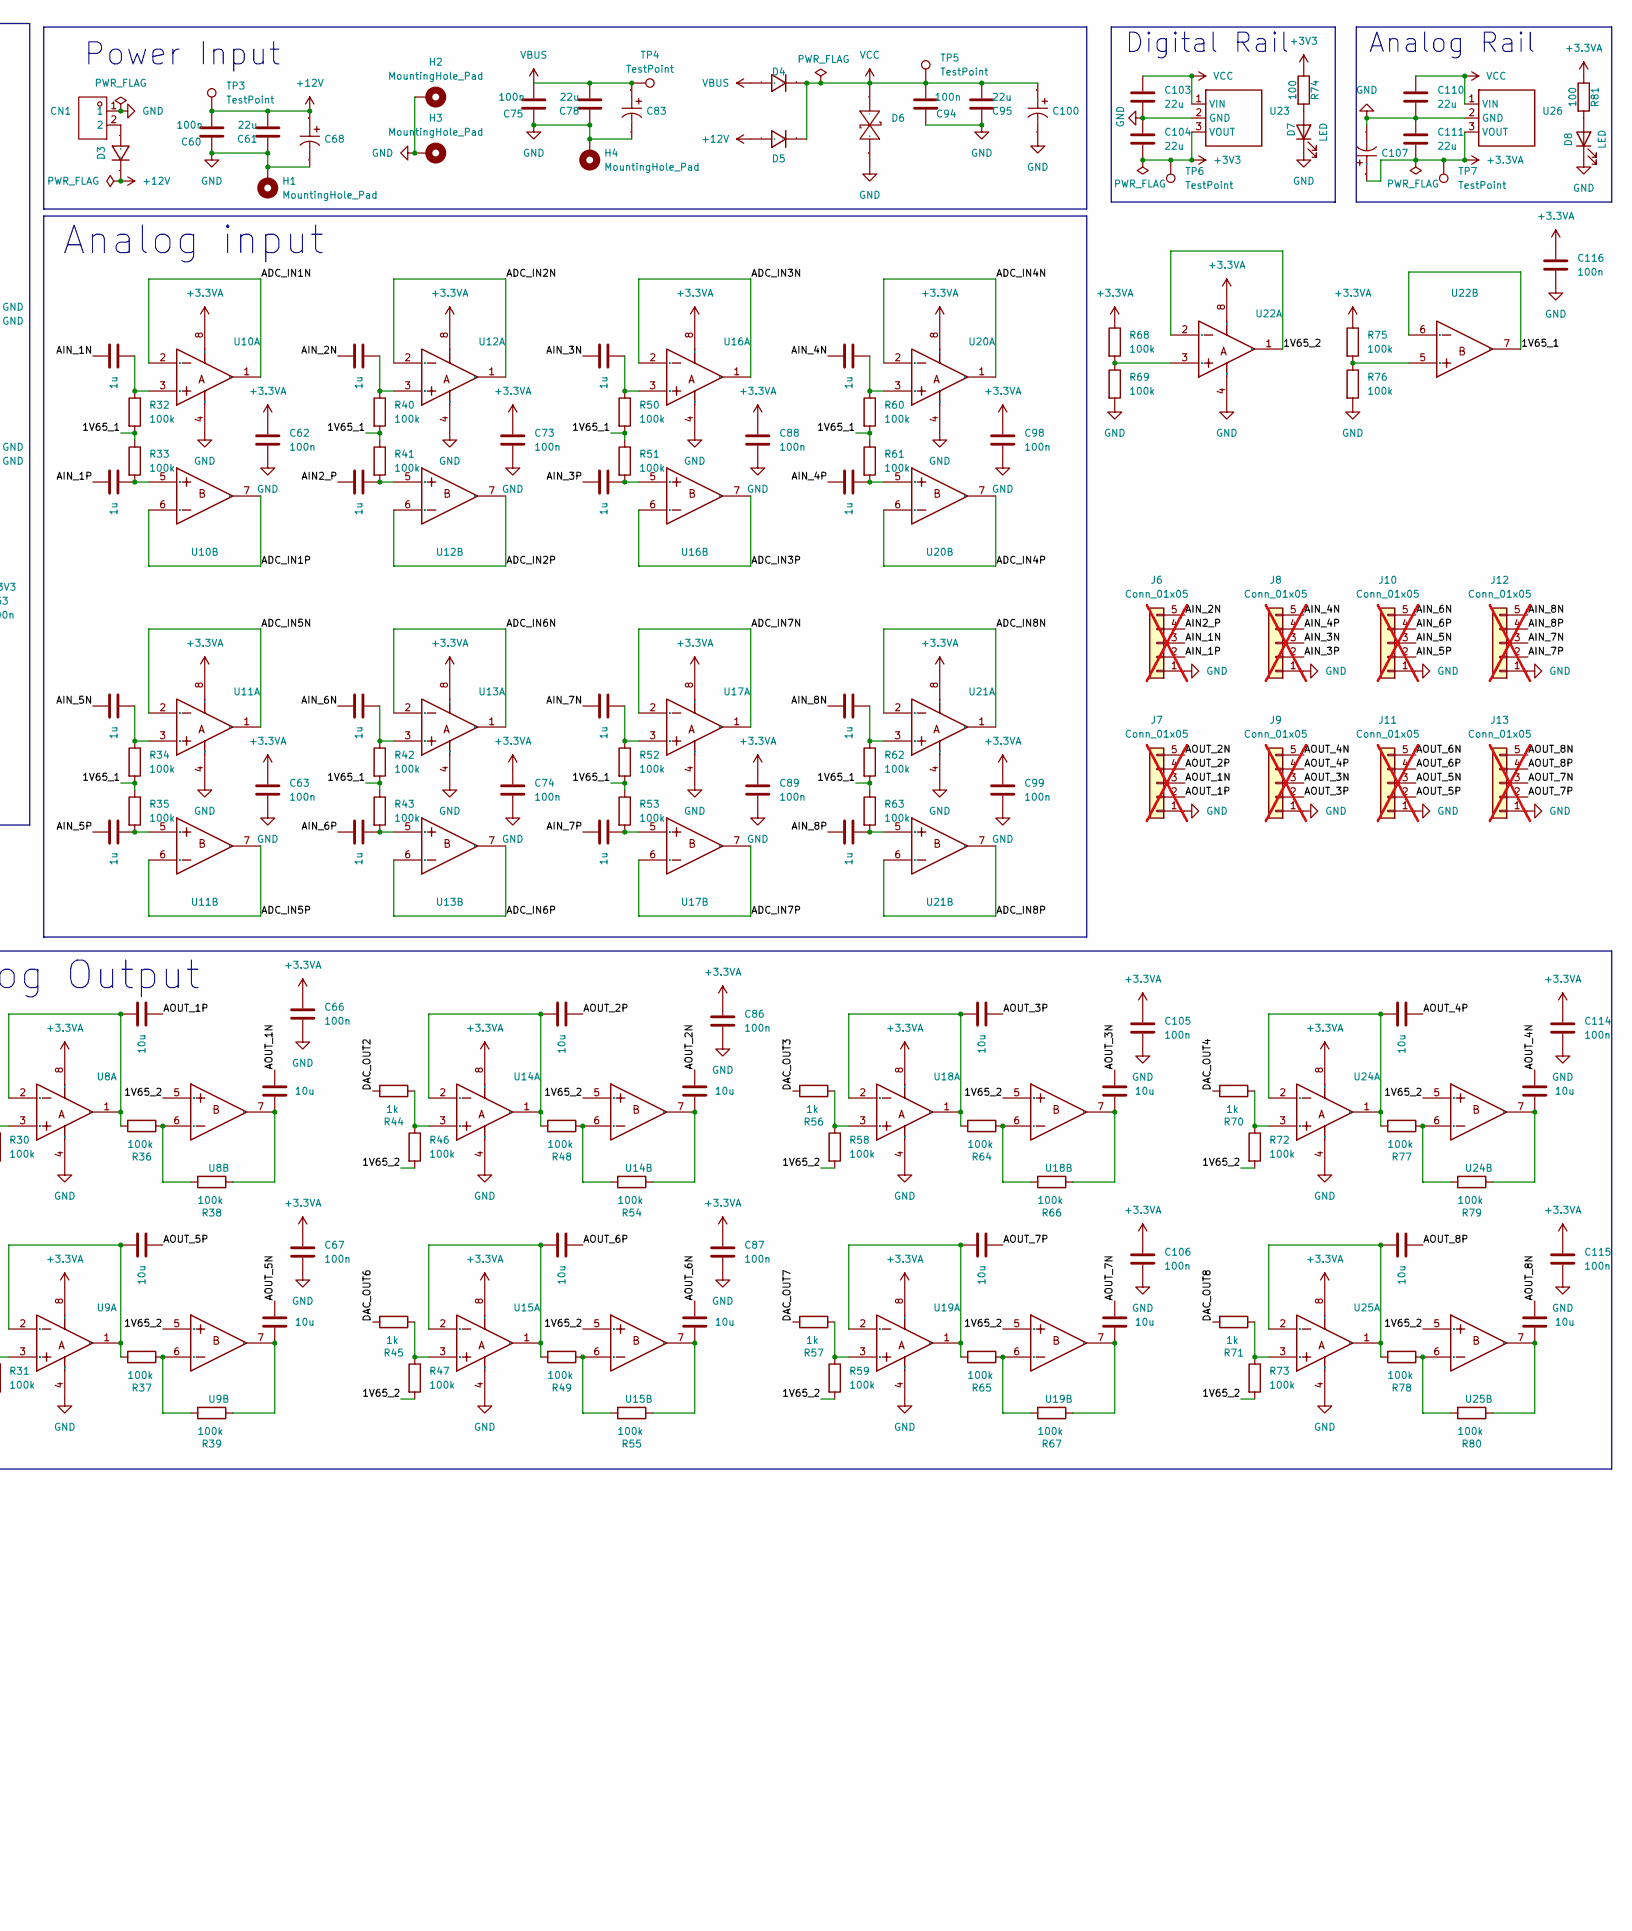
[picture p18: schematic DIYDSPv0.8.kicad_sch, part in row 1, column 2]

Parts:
C1, C3, C13, C18, C20, C21, C25, C26, C28, C42, C44, C58, C59, C64, C65, C76, C77, C84, C85, C96, C97, C101, C102, C108, C109, C112, C113: 10u; C_0603_1608Metric; LCSC Part # C96446
C2, C4, C9, C10: 2.2u; C_0402_1005Metric; LCSC Part # C12530
C5, C6, C11, C12, C14, C15, C19, C22, C23, C24, C27, C33, C36, C38, C39, C40, C41, C47, C48, C49, C51, C52, C53, C60, C62, C63, C66, C67, C73, C74, C75, C86, C87, C88, C89, C94, C98, C99, C105, C106, C114, C115, C116: 100n; C_0402_1005Metric; LCSC Part # C307331
C7, C8: 22p; C_0402_1005Metric; LCSC Part # C1555
C16, C17, C34, C35: 10n; C_0402_1005Metric; LCSC Part # C15195
C29: 4.7n; C_0402_1005Metric; LCSC Part # C1538
C30, C31, C45, C46, C54, C55, C56, C57, C69, C70, C71, C72, C79, C80, C81, C82, C90, C91, C92, C93: 1u; C_0402_1005Metric; LCSC Part # C52923
C32: 1n; C_0402_1005Metric; LCSC Part # C1523
C37: 100p; C_0402_1005Metric; LCSC Part # C1546
C43: 47p; C_0402_1005Metric; LCSC Part # C1567
C50, C61, C78, C95, C103, C104, C110, C111: 22u; C_0805_2012Metric; LCSC Part # C45783
C68, C83, C100, C107: 220uF; RVT1V221M0810; Manufacturer Part RVT1V221M0810; LCSC Part Name 220uF ±20% 35V
CN1: MX126-5.0-02P-GN01-Cu-S-A; Manufacturer Part MX126-5.0-02P-GN01-Cu-S-A; LCSC Part Name 1x2P 5mm 直插 排数:1 每排P数:2
D1, D2, D7, D8: LED; LED_0805_2012Metric; LCSC Part # C84256
D3, D4, D5: CUS08F30,H3F; Manufacturer Part CUS08F30,H3F; LCSC Part Name 电压:30V 电流:800mA
D6: SMF20CA; Manufacturer Part SMF20CA; LCSC Part Name 双向TVS 20V截止 峰值浪涌电流：6.2A
H1, H2, H3, H4: MountingHole_Pad; MountingHole_3.2mm_M3_Pad_TopBottom
J1: Conn_01x06; PinHeader_1x06_P2.54mm_Vertical; not fitted
J2, J6, J7, J8, J9, J10, J11, J12, J13: Conn_01x05; PinHeader_1x05_P2.54mm_Vertical; not fitted
J3, J4: Conn_01x04; PinHeader_1x04_P2.54mm_Vertical; not fitted
J5: Conn_01x02; PinHeader_1x02_P2.54mm_Vertical; not fitted
R1, R2, R3, R4, R5, R6, R7, R8, R9, R10, R11, R14, R19, R20, R25, R74, R81: 100; R_0805_2012Metric; LCSC Part # C17408
R12, R13, R21, R26, R27: 10k; R_0402_1005Metric; LCSC Part # C25744
R15, R18, R28, R29, R44, R45, R56, R57, R70, R71: 1k; R_0402_1005Metric; LCSC Part # C11702
R16, R17: 2.2k; R_0402_1005Metric; LCSC Part # C25879
R22, R30, R31, R32, R33, R34, R35, R36, R37, R38, R39, R40, R41, R42, R43, R46, R47, R48, R49, R50, R51, R52, R53, R54, R55, R58, R59, R60, R61, R62, R63, R64, R65, R66, R67, R68, R69, R72, R73, R75, R76, R77, R78, R79, R80: 100k; R_0402_1005Metric; LCSC Part # C25741
R23, R24: 5.1k; R_0402_1005Metric; LCSC Part # C25905
SW1, SW2, SW3: TS110916043; Manufacturer Part TS110916043; LCSC Part Name TS110916043
TP1: TestPoint; TestPoint_THTPad_D4.0mm_Drill2.0mm
TP2, TP3, TP4, TP5, TP6, TP7: TestPoint; TestPoint_THTPad_D2.0mm_Drill1.0mm
U1: ADAU1452; ADAU1452WBCPZ-RL; Manufacturer Part ADAU1452WBCPZ-RL; LCSC Part Name SigmaDSP 数字音频处理器
U2, U3: AK4619VN; Manufacturer Part AK4619VN; LCSC Part Name AK4619VN
U4: AMS1117-1.2; Manufacturer Part AMS1117-1.2; LCSC Part Name 1.2V 1A 15V
U5: ESP32-S3-WROOM-1U-N8; Manufacturer Part ESP32-S3-WROOM-1U-N8; LCSC Part Name 通用型Wi-Fi+低功耗蓝牙MCU模组
U6: ADM811TARTZ-REEL7; Manufacturer Part ADM811TARTZ-REEL7; LCSC Part Name 4引脚SOT-143微处理器监控电路
U7: GT-USB-7010ASV; Manufacturer Part GT-USB-7010ASV; LCSC Part Name Type-C 母 卧贴
U8, U9, U10, U11, U12, U13, U14, U15, U16, U17, U18, U19, U20, U21, U22, U24, U25: TLV9062IDR; Manufacturer Part TLV9062IDR; LCSC Part Name 适用于成本敏感型系统的10MHz、轨到轨输入输出（RRIO）CMOS运算放大器
U23, U26: K7803-1000_C50396471; Manufacturer Part K7803-1000; LCSC Part Name DC-DC模块电源，宽电压输入，非隔离稳压单路输出
X1: 12.288MHz; S47SMD12.288M20PF20R30B3; Manufacturer Part S47SMD12.288M20PF20R30B3; LCSC Part Name 12.288MHz ±20ppm 20pF

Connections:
+1V2: C16.1, C17.2, C22.1, C23.2, C30.1, C31.2, C34.2, C35.2, C38.1, C40.2, C41.2, C44.1, C45.2, C46.2, TP2.1, U1.20 (DVDD), U1.35 (DVDD), U1.53 (DVDD), U1.71 (DVDD), U4.2 (OUT)
+3.3VA: C11.2, C12.2, C13.2, C18.1, C20.1, C21.2, C24.2, C27.2, C62.1, C63.1, C66.1, C67.1, C73.1, C74.1, C86.1, C87.1, C88.1, C89.1, C98.1, C99.1, C105.1, C106.1, C107.1, C111.1, C114.1, C115.1, C116.1, R68.1, R75.1, R81.1, TP7.1, U2.18 (AVDD), U2.21 (VREFH), U3.18 (AVDD), U3.21 (VREFH), U8.8 (VCC), U9.8 (VCC), U10.8 (VCC), U11.8 (VCC), U12.8 (VCC), U13.8 (VCC), U14.8 (VCC), U15.8 (VCC), U16.8 (VCC), U17.8 (VCC), U18.8 (VCC), U19.8 (VCC), U20.8 (VCC), U21.8 (VCC), U22.8 (VCC), U24.8 (VCC), U25.8 (VCC), U26.3 (VOUT)
+3V3: C1.2, C3.2, C5.2, C6.2, C14.1, C15.1, C19.1, C25.2, C26.1, C28.1, C29.1, C32.1, C33.1, C36.1, C37.1, C39.1, C42.1, C43.1, C47.1, C50.1, C52.1, C53.2, C104.1, J4.3, J4.4, R13.1, R15.1, R18.1, R26.2, R27.1, R74.1, TP6.1, U1.2 (IOVDD), U1.7 (AVDD), U1.15 (PVDD), U1.18 (IOVDD), U1.38 (IOVDD), U1.56 (IOVDD), U2.3 (TVDD), U3.3 (TVDD), U4.3 (IN), U5.2 (3V3), U6.4 (VCC), U23.3 (VOUT)
+12V: C60.2, C61.2, C68.1, D3.1 (C), D5.2 (A), TP3.1
/1V65_1: R32.2, R33.1, R34.2, R35.1, R40.2, R41.1, R42.2, R43.1, R50.2, R51.1, R52.2, R53.1, R60.2, R61.1, R62.2, R63.1, U22.6 (INB-), U22.7 (OUTB)
/1V65_2: R30.2, R31.2, R46.2, R47.2, R58.2, R59.2, R72.2, R73.2, U8.5 (INB+), U9.5 (INB+), U14.5 (INB+), U15.5 (INB+), U18.5 (INB+), U19.5 (INB+), U22.1 (OUTA), U22.2 (INA-), U24.5 (INB+), U25.5 (INB+)
/ADC_IN1N: U2.15 (IN1N/AIN2L/GND3L), U10.1 (OUTA), U10.2 (INA-)
/ADC_IN1P: U2.16 (IN1P/AIN1L/AIN3L), U10.6 (INB-), U10.7 (OUTB)
/ADC_IN2N: U2.13 (IN2N/AIN2R/GND3R), U12.1 (OUTA), U12.2 (INA-)
/ADC_IN2P: U2.14 (IN2P/AIN1R/AIN3R), U12.6 (INB-), U12.7 (OUTB)
/ADC_IN3N: U2.11 (IN3N/AIN5L/GND6L), U16.1 (OUTA), U16.2 (INA-)
/ADC_IN3P: U2.12 (IN3P/AIN4L/AIN6L), U16.6 (INB-), U16.7 (OUTB)
/ADC_IN4N: U2.9 (IN4N/AIN5R/GND6R), U20.1 (OUTA), U20.2 (INA-)
/ADC_IN4P: U2.10 (IN4P/AIN4R/AIN6R), U20.6 (INB-), U20.7 (OUTB)
/ADC_IN5N: U3.15 (IN1N/AIN2L/GND3L), U11.1 (OUTA), U11.2 (INA-)
/ADC_IN5P: U3.16 (IN1P/AIN1L/AIN3L), U11.6 (INB-), U11.7 (OUTB)
/ADC_IN6N: U3.13 (IN2N/AIN2R/GND3R), U13.1 (OUTA), U13.2 (INA-)
/ADC_IN6P: U3.14 (IN2P/AIN1R/AIN3R), U13.6 (INB-), U13.7 (OUTB)
/ADC_IN7N: U3.11 (IN3N/AIN5L/GND6L), U17.1 (OUTA), U17.2 (INA-)
/ADC_IN7P: U3.12 (IN3P/AIN4L/AIN6L), U17.6 (INB-), U17.7 (OUTB)
/ADC_IN8N: U3.9 (IN4N/AIN5R/GND6R), U21.1 (OUTA), U21.2 (INA-)
/ADC_IN8P: U3.10 (IN4P/AIN4R/AIN6R), U21.6 (INB-), U21.7 (OUTB)
/AIN2_P: C70.2, J6.4
/AIN_1N: C54.2, J6.3
/AIN_1P: C55.2, J6.2
/AIN_2N: C69.2, J6.5
/AIN_3N: C79.2, J8.3
/AIN_3P: C80.2, J8.2
/AIN_4N: C90.2, J8.5
/AIN_4P: C91.2, J8.4
/AIN_5N: C56.2, J10.3
/AIN_5P: C57.2, J10.2
/AIN_6N: C71.2, J10.5
/AIN_6P: C72.2, J10.4
/AIN_7N: C81.2, J12.3
/AIN_7P: C82.2, J12.2
/AIN_8N: C92.2, J12.5
/AIN_8P: C93.2, J12.4
/AOUT_1N: C64.1, J7.3
/AOUT_1P: C58.1, J7.2
/AOUT_2N: C84.1, J7.5
/AOUT_2P: C76.1, J7.4
/AOUT_3N: C101.1, J9.3
/AOUT_3P: C96.1, J9.2
/AOUT_4N: C112.1, J9.5
/AOUT_4P: C108.1, J9.4
/AOUT_5N: C65.1, J11.3
/AOUT_5P: C59.1, J11.2
/AOUT_6N: C85.1, J11.5
/AOUT_6P: C77.1, J11.4
/AOUT_7N: C102.1, J13.3
/AOUT_7P: C97.1, J13.2
/AOUT_8N: C113.1, J13.5
/AOUT_8P: C109.1, J13.4
/AUXADC0: J1.1, U1.8 (AUXADC0)
/AUXADC1: J1.2, U1.9 (AUXADC1)
/AUXADC2: J1.3, U1.10 (AUXADC2)
/AUXADC3: J1.4, U1.11 (AUXADC3)
/AUXADC4: J1.5, U1.12 (AUXADC4)
/AUXADC5: J1.6, U1.13 (AUXADC5)
/BCLK_OUT0: R6.1, U1.40 (BCLK_OUT0), U1.57 (BCLK_IN0)
/BCLK_OUT1: R3.1, U1.43 (BCLK_OUT1), U1.60 (BCLK_IN1)
/CODEC_EN: R15.2, U2.26 (PDN), U3.26 (PDN), U5.22 (IO14)
/DAC_OUT1: R28.2, U2.22 (AOUT1L)
/DAC_OUT2: R44.2, U2.23 (AOUT1R)
/DAC_OUT3: R56.2, U2.24 (AOUT2L)
/DAC_OUT4: R70.2, U2.25 (AOUT2R)
/DAC_OUT5: R29.2, U3.22 (AOUT1L)
/DAC_OUT6: R45.2, U3.23 (AOUT1R)
/DAC_OUT7: R57.2, U3.24 (AOUT2L)
/DAC_OUT8: R71.2, U3.25 (AOUT2R)
/DSP_MISO: U1.30 (MISO/SDA), U5.21 (IO13)
/DSP_MOSI: U1.32 (MOSI/ADDR1), U5.19 (IO11)
/DSP_SCLK: U1.31 (SCLK/SCL), U5.20 (IO12)
/DSP_SS: U1.33 (SS/ADDR0), U5.18 (IO10)
/DSP_nRESET: R18.2, U1.24 (RESET#), U5.17 (IO9)
/EN: C48.1, R21.1, SW1.3, U5.3 (EN)
/HB_LED1: R25.2, U5.39 (IO1)
/HB_LED2: R14.1, U1.46 (MP7)
/IO0: C49.2, SW2.2, U5.27 (IO0)
/LRCLK_OUT0: R5.1, U1.39 (LRCLK_OUT0/MP4), U1.58 (LRCLK_IN0/MP10)
/LRCLK_OUT1: R2.1, U1.42 (LRCLK_OUT1/MP5), U1.61 (LRCLK_IN1/MP11)
/MCLK: R4.1, R7.1, U1.23 (CLKOUT)
/MCU_USB_DN: R19.2, U5.13 (IO19)
/MCU_USB_DP: R20.1, U5.14 (IO20)
/MP0: J2.1, U1.26 (SS_M/MP0)
/MP1: J2.2, U1.27 (MOSI_M/MP1)
/MP2: J2.3, U1.28 (SCL_M/SCLK_M/MP2)
/MP3: J2.4, U1.29 (SDA_M/MISO_M/MP3)
/MP6: J2.5, U1.45 (MP6)
/PLLFILT: C37.2, C43.2, R17.2, U1.16 (PLLFILT)
/RXD0: J3.3, U5.36 (RXD0)
/SCL: J5.2, R27.2, U2.28 (SCL/SCLK), U3.28 (SCL/SCLK), U5.5 (IO5)
/SDA: J5.1, R26.1, U2.30 (SDA/SO), U3.30 (SDA/SO), U5.4 (IO4)
/SDATA_IN0: R11.1, U1.59 (SDATA_IN0)
/SDATA_IN1: R10.1, U1.62 (SDATA_IN1)
/SDATA_OUT0: R9.1, U1.41 (SDATA_OUT0)
/SDATA_OUT1: R8.1, U1.44 (SDATA_OUT1)
/TXD0: J3.2, U5.37 (TXD0)
/USB_DN: R19.1, U7.A7 (DN1), U7.B7 (DN2)
/USB_DP: R20.2, U7.A6 (DP1), U7.B6 (DP2)
/XTALIN: C7.2, U1.21 (XTALIN/MCLK), X1.2
/XTALOUT: R1.1, U1.22 (XTALOUT)
GND: C1.1, C2.1, C3.1, C4.1, C5.1, C6.1, C7.1, C8.2, C9.1, C10.1, C11.1, C12.1, C13.1, C14.2, C15.2, C16.2, C17.1, C18.2, C19.2, C20.2, C21.1, C22.2, C23.1, C24.1, C25.1, C26.2, C27.1, C28.2, C30.2, C31.1, C33.2, C34.1, C35.1, C36.2, C38.2, C39.2, C40.1, C41.1, C42.2, C44.2, C45.1, C46.1, C47.2, C48.2, C49.1, C50.2, C51.2, C52.2, C53.1, C60.1, C61.1, C62.2, C63.2, C66.2, C67.2, C68.2, C73.2, C74.2, C75.1, C78.1, C83.2, C86.2, C87.2, C88.2, C89.2, C94.1, C95.1, C98.2, C99.2, C100.2, C103.1, C104.2, C105.2, C106.2, C107.2, C110.2, C111.2, C114.2, C115.2, C116.2, CN1.1, D1.1 (K), D2.1 (K), D6.1, D7.1 (K), D8.1 (K), H1.1, H2.1, H3.1, H4.1, J3.1, J4.1, J4.2, J6.1, J7.1, J8.1, J9.1, J10.1, J11.1, J12.1, J13.1, R12.1, R22.2, R23.1, R24.2, R69.2, R76.2, SW1.4, SW2.1, SW3.4, TP1.1, U1.1 (DGND), U1.3 (VDRIVE), U1.6 (AGND), U1.14 (PGND), U1.17 (DGND), U1.19 (DGND), U1.25 (DGND), U1.34 (SELFBOOT), U1.36 (DGND), U1.37 (DGND), U1.54 (DGND), U1.55 (DGND), U1.72 (DGND), U1.73 (EP), U2.4 (Vss2), U2.19 (VSS1), U2.20 (VREFL), U2.33 (EP), U3.4 (Vss2), U3.19 (VSS1), U3.20 (VREFL), U3.33 (EP), U4.1 (ADJ/GND), U5.1 (GND), U5.40 (GND), U5.41 (GND), U6.1 (GND), U7.1 (SHELL), U7.2 (SHELL), U7.3 (SHELL), U7.4 (SHELL), U7.A1B12 (GND), U7.B1A12 (GND), U8.4 (VEE/GND), U9.4 (VEE/GND), U10.4 (VEE/GND), U11.4 (VEE/GND), U12.4 (VEE/GND), U13.4 (VEE/GND), U14.4 (VEE/GND), U15.4 (VEE/GND), U16.4 (VEE/GND), U17.4 (VEE/GND), U18.4 (VEE/GND), U19.4 (VEE/GND), U20.4 (VEE/GND), U21.4 (VEE/GND), U22.4 (VEE/GND), U23.2 (GND), U24.4 (VEE/GND), U25.4 (VEE/GND), U26.2 (GND)
unnamed: C8.1, R1.2, X1.1
unnamed: C29.2, C32.2, R16.1
unnamed: D1.2 (A), R14.2
unnamed: D2.2 (A), R25.1
unnamed: CN1.2, D3.2 (A)
unnamed: D7.2 (A), R74.2
unnamed: D8.2 (A), R81.2
unnamed: R16.2, R17.1
unnamed: C2.2, U2.5 (AVDRV)
unnamed: R3.2, U2.7 (BICK)
unnamed: R12.2, U2.27 (CAD/CSN)
unnamed: R2.2, U2.6 (LRCK)
unnamed: R4.2, U2.8 (MCLK)
unnamed: R8.2, U2.1 (SDIN1)
unnamed: R10.2, U2.31 (SDOUT1)
unnamed: C9.2, U2.17 (VCOM)
unnamed: C4.2, U3.5 (AVDRV)
unnamed: R6.2, U3.7 (BICK)
unnamed: R13.2, U3.27 (CAD/CSN)
unnamed: R5.2, U3.6 (LRCK)
unnamed: R7.2, U3.8 (MCLK)
unnamed: R9.2, U3.1 (SDIN1)
unnamed: R11.2, U3.31 (SDOUT1)
unnamed: C10.2, U3.17 (VCOM)
unnamed: C51.1, SW3.3, U6.3 (MR#)
unnamed: R21.2, R22.1, U6.2 (RESET#/RESET)
unnamed: R23.2, U7.A5 (CC1)
unnamed: R24.1, U7.B5 (CC2)
unnamed: R28.1, R30.1, U8.3 (INA+)
unnamed: C58.2, R36.2, U8.1 (OUTA), U8.2 (INA-)
unnamed: R36.1, R38.2, U8.6 (INB-)
unnamed: C64.2, R38.1, U8.7 (OUTB)
unnamed: R29.1, R31.1, U9.3 (INA+)
unnamed: C59.2, R37.2, U9.1 (OUTA), U9.2 (INA-)
unnamed: R37.1, R39.2, U9.6 (INB-)
unnamed: C65.2, R39.1, U9.7 (OUTB)
unnamed: C54.1, R32.1, U10.3 (INA+)
unnamed: C55.1, R33.2, U10.5 (INB+)
unnamed: C56.1, R34.1, U11.3 (INA+)
unnamed: C57.1, R35.2, U11.5 (INB+)
unnamed: C69.1, R40.1, U12.3 (INA+)
unnamed: C70.1, R41.2, U12.5 (INB+)
unnamed: C71.1, R42.1, U13.3 (INA+)
unnamed: C72.1, R43.2, U13.5 (INB+)
unnamed: R44.1, R46.1, U14.3 (INA+)
unnamed: C76.2, R48.2, U14.1 (OUTA), U14.2 (INA-)
unnamed: R48.1, R54.2, U14.6 (INB-)
unnamed: C84.2, R54.1, U14.7 (OUTB)
unnamed: R45.1, R47.1, U15.3 (INA+)
unnamed: C77.2, R49.2, U15.1 (OUTA), U15.2 (INA-)
unnamed: R49.1, R55.2, U15.6 (INB-)
unnamed: C85.2, R55.1, U15.7 (OUTB)
unnamed: C79.1, R50.1, U16.3 (INA+)
unnamed: C80.1, R51.2, U16.5 (INB+)
unnamed: C81.1, R52.1, U17.3 (INA+)
unnamed: C82.1, R53.2, U17.5 (INB+)
unnamed: R56.1, R58.1, U18.3 (INA+)
unnamed: C96.2, R64.2, U18.1 (OUTA), U18.2 (INA-)
unnamed: R64.1, R66.2, U18.6 (INB-)
unnamed: C101.2, R66.1, U18.7 (OUTB)
unnamed: R57.1, R59.1, U19.3 (INA+)
unnamed: C97.2, R65.2, U19.1 (OUTA), U19.2 (INA-)
unnamed: R65.1, R67.2, U19.6 (INB-)
unnamed: C102.2, R67.1, U19.7 (OUTB)
unnamed: C90.1, R60.1, U20.3 (INA+)
unnamed: C91.1, R61.2, U20.5 (INB+)
unnamed: C92.1, R62.1, U21.3 (INA+)
unnamed: C93.1, R63.2, U21.5 (INB+)
unnamed: R68.2, R69.1, U22.3 (INA+)
unnamed: R75.2, R76.1, U22.5 (INB+)
unnamed: R70.1, R72.1, U24.3 (INA+)
unnamed: C108.2, R77.2, U24.1 (OUTA), U24.2 (INA-)
unnamed: R77.1, R79.2, U24.6 (INB-)
unnamed: C112.2, R79.1, U24.7 (OUTB)
unnamed: R71.1, R73.1, U25.3 (INA+)
unnamed: C109.2, R78.2, U25.1 (OUTA), U25.2 (INA-)
unnamed: R78.1, R80.2, U25.6 (INB-)
unnamed: C113.2, R80.1, U25.7 (OUTB)
VBUS: C75.2, C78.2, C83.1, D4.2 (A), TP4.1, U7.A4B9 (VBUS), U7.B4A9 (VBUS)
VCC: C94.2, C95.2, C100.1, C103.2, C110.1, D4.1 (C), D5.1 (C), D6.2, TP5.1, U23.1 (VIN), U26.1 (VIN)

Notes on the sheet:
Analog input
Pin15
Pin56
ESP32
ADAU1452
Pin7
Pin53
Analog Rail
1.2V Generation
Pin20
AMS1117-1.2
Pin35
Pin2
Pin18
Analog Output
AK4619
Power Input
Pin71
Pin38
Digital Rail

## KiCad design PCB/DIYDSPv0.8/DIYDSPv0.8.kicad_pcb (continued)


Board: 4 copper layers, 100.0 x 65.0 mm, 260 parts (0 on the bottom side), 184 nets.

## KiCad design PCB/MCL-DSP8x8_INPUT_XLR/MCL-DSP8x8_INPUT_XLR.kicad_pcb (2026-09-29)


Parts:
J1: Conn_01x05; PinHeader_1x05_P2.54mm_Vertical; not fitted
PS1, PS2: NC3FAAH1; Manufacturer Part NC3FAAH1; LCSC Part Name NC3FAAH1
R1, R3, R5, R7: 82k; R_0805_2012Metric_Pad1.20x1.40mm_HandSolder; LCSC Part # C22356755
R2, R4, R6, R8: 10k; R_0805_2012Metric_Pad1.20x1.40mm_HandSolder; LCSC Part # C3152175

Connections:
/IN_A+: J1.2, R1.2, R2.1
/IN_A-: J1.3, R5.2, R6.1
/IN_B+: J1.4, R3.2, R4.1
/IN_B-: J1.5, R7.2, R8.1
/XLR_1+: PS1.2, R1.1
/XLR_1-: PS1.3, R5.1
/XLR_2+: PS2.2, R3.1
/XLR_2-: PS2.3, R7.1
GND: J1.1, PS1.1, PS2.1, R2.2, R4.2, R6.2, R8.2


Board: 2 copper layers, 60.0 x 34.0 mm, 11 parts (0 on the bottom side), 9 nets.

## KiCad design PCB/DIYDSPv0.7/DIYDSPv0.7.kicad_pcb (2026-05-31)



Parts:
C1, C3, C14, C19, C24, C25, C27, C31, C32, C34, C51: 10u; C_0603_1608Metric; LCSC Part # C96446
C2, C4, C15, C16: 2.2u; C_0402_1005Metric; LCSC Part # C12530
C5, C6, C13, C17, C18, C20, C21, C26, C28, C29, C30, C33, C39, C43, C44, C45, C46, C48, C52, C53, C54, C56, C57: 100n; C_0402_1005Metric; LCSC Part # C307331
C7, C10, C11, C12, C55: 22u; C_0805_2012Metric; LCSC Part # C45783
C8, C9: 22p; C_0402_1005Metric; LCSC Part # C1555
C22, C23, C40, C41: 10n; C_0402_1005Metric; LCSC Part # C15195
C35: 4.7n; C_0402_1005Metric; LCSC Part # C1538
C36, C37, C49, C50, C58, C59, C60, C61, C62, C63, C64, C65, C66, C67, C68, C69, C70, C71, C72, C73, C74, C75, C76, C77, C78, C79, C80, C81: 1u; C_0402_1005Metric; LCSC Part # C52923
C38: 1n; C_0402_1005Metric; LCSC Part # C1523
C42: 100p; C_0402_1005Metric; LCSC Part # C1546
C47: 47p; C_0402_1005Metric; LCSC Part # C1567
CN1: MX126-5.0-02P-GN01-Cu-S-A; Manufacturer Part MX126-5.0-02P-GN01-Cu-S-A; LCSC Part Name 1x2P 5mm 直插 排数:1 每排P数:2
D1: SMF20CA; Manufacturer Part SMF20CA; LCSC Part Name 双向TVS 20V截止 峰值浪涌电流：6.2A
D2, D3, D4: LED; LED_0805_2012Metric; LCSC Part # C84256
J1: Conn_01x06; PinHeader_1x06_P2.54mm_Vertical
J2, J3: Conn_01x04; PinHeader_1x04_P2.54mm_Vertical
J4: Conn_01x05; PinHeader_1x05_P2.54mm_Vertical
J5: Conn_01x01; PinHeader_1x01_P2.54mm_Vertical
J6: Conn_01x02; PinHeader_1x02_P2.54mm_Vertical
R1, R2, R3, R4, R5, R6, R7, R8, R9, R10, R11, R17, R18, R19, R23, R24: 100; R_0805_2012Metric; LCSC Part # C17408
R12, R13, R25, R26, R27, R28: 10k; R_0402_1005Metric; LCSC Part # C25744
R14, R29, R30, R37, R38, R39, R40, R41, R42, R43, R44, R45, R46, R49, R50, R57, R58, R59, R60, R61, R62, R63, R64, R65, R66: 100k; R_0402_1005Metric; LCSC Part # C25741
R15, R16: 2.2k; R_0402_1005Metric; LCSC Part # C25879
R20: 1k; R_0402_1005Metric; LCSC Part # C11702
R21, R22: 5.1k; R_0402_1005Metric; LCSC Part # C25905
R31, R32, R33, R34, R35, R36, R47, R48, R51, R52, R53, R54, R55, R56, R67, R68: 220k; R_0603_1608Metric; LCSC Part # C22961
TP1, TP3, TP4, TP6: TestPoint; TestPoint_THTPad_D4.0mm_Drill2.0mm
TP2, TP5, TP7, TP8, TP9, TP10, TP11, TP12, TP13, TP14, TP15: TestPoint; TestPoint_THTPad_D2.0mm_Drill1.0mm
U1: ADAU1452; ADAU1452WBCPZ-RL; Manufacturer Part ADAU1452WBCPZ-RL; LCSC Part Name SigmaDSP 数字音频处理器
U2, U3: AK4619VN; Manufacturer Part AK4619VN; LCSC Part Name AK4619VN
U4: K7803M-1000R3; Manufacturer Part K7803M-1000R3; LCSC Part Name DCDC电源模块
U5: AMS1117-1.2; Manufacturer Part AMS1117-1.2; LCSC Part Name 1.2V 1A 15V
U6: ADM811TARTZ-REEL7; Manufacturer Part ADM811TARTZ-REEL7; LCSC Part Name 4引脚SOT-143微处理器监控电路
U7, U18, U19: YTS1C0033BBG01; Manufacturer Part YTS1C0033BBG01; LCSC Part Name 侧按键3x6x3.8 黑钮贴片
U8, U9, U11, U12, U13, U14, U15, U16: PJ-320D; Manufacturer Part PJ-320D; LCSC Part Name 3.5mm耳机座
U10: GT-USB-7010ASV; Manufacturer Part GT-USB-7010ASV; LCSC Part Name Type-C 母 卧贴
U17: ESP32-S3-WROOM-1U-N8; Manufacturer Part ESP32-S3-WROOM-1U-N8; LCSC Part Name 通用型Wi-Fi+低功耗蓝牙MCU模组
U20, U21, U22, U23: LM324DT; Manufacturer Part LM324DT; LCSC Part Name 低功耗四路运算放大器
X1: 12.288MHz; S47SMD12.288M20PF20R30B3; Manufacturer Part S47SMD12.288M20PF20R30B3; LCSC Part Name 12.288MHz ±20ppm 20pF

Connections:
+1V2: C22.1, C23.2, C26.1, C28.1, C29.2, C34.1, C36.1, C37.2, C40.2, C41.2, C45.2, C46.2, C49.2, C50.2, TP7.1, U1.20 (DVDD), U1.35 (DVDD), U1.53 (DVDD), U1.71 (DVDD), U5.2 (OUT)
+3V3: C1.2, C3.2, C5.2, C6.2, C12.1, C13.1, C14.1, C17.2, C18.2, C19.2, C20.1, C21.1, C24.1, C25.1, C27.2, C30.2, C31.2, C32.1, C33.2, C35.1, C38.1, C39.1, C42.1, C43.1, C44.1, C47.1, C51.1, C52.1, C55.1, C57.1, J3.3, J3.4, R13.1, R19.1, R20.1, R26.1, R27.2, R28.1, TP5.1, U1.2 (IOVDD), U1.7 (AVDD), U1.15 (PVDD), U1.18 (IOVDD), U1.38 (IOVDD), U1.56 (IOVDD), U2.3 (TVDD), U2.18 (AVDD), U2.21 (VREFH), U3.3 (TVDD), U3.18 (AVDD), U3.21 (VREFH), U4.3 (Vo), U5.3 (IN), U17.2 (3V3)
+12V: C7.2, C10.2, C11.1, CN1.2, D1.2, R37.1, R38.1, R39.1, R40.1, R57.1, R58.1, R59.1, R60.1, TP2.1, U4.1 (Vin), U20.4 (VCC+), U21.4 (VCC+), U22.4 (VCC+), U23.4 (VCC+)
/ADC_IN1: C64.2, U2.16 (IN1P/AIN1L/AIN3L)
/ADC_IN2: C65.2, U2.14 (IN2P/AIN1R/AIN3R)
/ADC_IN3: C76.2, U2.12 (IN3P/AIN4L/AIN6L)
/ADC_IN4: C77.2, U2.10 (IN4P/AIN4R/AIN6R)
/ADC_IN5: C66.2, U3.16 (IN1P/AIN1L/AIN3L)
/ADC_IN6: C67.2, U3.14 (IN2P/AIN1R/AIN3R)
/ADC_IN7: C78.2, U3.12 (IN3P/AIN4L/AIN6L)
/ADC_IN8: C79.2, U3.10 (IN4P/AIN4R/AIN6R)
/AUXADC0: J1.1, U1.8 (AUXADC0)
/AUXADC1: J1.2, U1.9 (AUXADC1)
/AUXADC2: J1.3, U1.10 (AUXADC2)
/AUXADC3: J1.4, U1.11 (AUXADC3)
/AUXADC4: J1.5, U1.12 (AUXADC4)
/AUXADC5: J1.6, U1.13 (AUXADC5)
/A_IN1: C58.1, U8.4
/A_IN2: C59.1, U8.3
/A_IN3: C70.1, U11.4
/A_IN4: C71.1, U11.3
/A_IN5: C60.1, U9.4
/A_IN6: C61.1, U9.3
/A_IN7: C72.1, U12.4
/A_IN8: C73.1, U12.3
/A_OUT1: C62.2, U13.4
/A_OUT2: C68.2, U13.3
/A_OUT3: C74.2, U15.4
/A_OUT4: C80.2, U15.3
/A_OUT5: C63.2, U14.4
/A_OUT6: C69.2, U14.3
/A_OUT7: C75.2, U16.4
/A_OUT8: C81.2, U16.3
/BCLK_OUT0: R6.1, U1.40 (BCLK_OUT0), U1.57 (BCLK_IN0)
/BCLK_OUT1: R3.1, U1.43 (BCLK_OUT1), U1.60 (BCLK_IN1)
/CODEC_PDN: R14.2, U2.26 (PDN), U3.26 (PDN), U6.2 (RESET#/RESET)
/DAC_OUT1: U2.22 (AOUT1L), U20.3 (IN1+)
/DAC_OUT2: U2.23 (AOUT1R), U20.5 (IN2+)
/DAC_OUT3: U2.24 (AOUT2L), U20.10 (IN3+)
/DAC_OUT4: U2.25 (AOUT2R), U20.12 (IN4+)
/DAC_OUT5: U3.22 (AOUT1L), U21.3 (IN1+)
/DAC_OUT6: U3.23 (AOUT1R), U21.5 (IN2+)
/DAC_OUT7: U3.24 (AOUT2L), U21.10 (IN3+)
/DAC_OUT8: U3.25 (AOUT2R), U21.12 (IN4+)
/DSP_MISO: U1.30 (MISO/SDA), U17.21 (IO13)
/DSP_MOSI: U1.32 (MOSI/ADDR1), U17.19 (IO11)
/DSP_SCLK: U1.31 (SCLK/SCL), U17.20 (IO12)
/DSP_SS: U1.33 (SS/ADDR0), U17.18 (IO10)
/DSP_nRESET: R20.2, U1.24 (RESET#), U17.17 (IO9)
/EN: C54.1, R26.2, U17.3 (EN), U19.2
/HB_LED1: R17.1, U17.39 (IO1)
/HB_LED2: R18.1, U1.46 (MP7)
/IO0: C56.2, R25.2, U17.27 (IO0), U18.2
/LRCLK_OUT0: R5.1, U1.39 (LRCLK_OUT0/MP4), U1.58 (LRCLK_IN0/MP10)
/LRCLK_OUT1: R2.1, U1.42 (LRCLK_OUT1/MP5), U1.61 (LRCLK_IN1/MP11)
/MCLK: R4.1, R7.1, U1.23 (CLKOUT)
/MCU_USB_DN: R23.2, U17.13 (IO19)
/MCU_USB_DP: R24.1, U17.14 (IO20)
/MP0: J4.1, U1.26 (SS_M/MP0)
/MP1: J4.2, U1.27 (MOSI_M/MP1)
/MP2: J4.3, U1.28 (SCL_M/SCLK_M/MP2)
/MP3: J4.4, U1.29 (SDA_M/MISO_M/MP3)
/MP6: J4.5, U1.45 (MP6)
/PLLFILT: C42.2, C47.2, R16.2, U1.16 (PLLFILT)
/RXD0: J2.3, U17.36 (RXD0)
/SCL: J6.2, R28.2, U2.28 (SCL/SCLK), U3.28 (SCL/SCLK), U17.5 (IO5)
/SDA: J6.1, R27.1, U2.30 (SDA/SO), U3.30 (SDA/SO), U17.4 (IO4)
/SDATA_IN0: R11.1, U1.59 (SDATA_IN0)
/SDATA_IN1: R10.1, U1.62 (SDATA_IN1)
/SDATA_OUT0: R9.1, U1.41 (SDATA_OUT0)
/SDATA_OUT1: R8.1, U1.44 (SDATA_OUT1)
/TXD0: J2.2, U17.37 (TXD0)
/USB_DN: R23.1, U10.A7 (DN1), U10.B7 (DN2)
/USB_DP: R24.2, U10.A6 (DP1), U10.B6 (DP2)
/XTALIN: C8.2, U1.21 (XTALIN/MCLK), X1.2
/XTALOUT: R1.1, U1.22 (XTALOUT)
GND: C1.1, C2.1, C3.1, C4.1, C5.1, C6.1, C7.1, C8.1, C9.2, C10.1, C11.2, C12.2, C13.2, C14.2, C15.1, C16.1, C17.1, C18.1, C19.1, C20.2, C21.2, C22.2, C23.1, C24.2, C25.2, C26.2, C27.1, C28.2, C29.1, C30.1, C31.1, C32.2, C33.1, C34.2, C36.2, C37.1, C39.2, C40.1, C41.1, C43.2, C44.2, C45.1, C46.1, C48.1, C49.1, C50.1, C51.2, C52.2, C53.1, C54.2, C55.2, C56.1, C57.2, CN1.1, D1.1, D2.1 (K), D3.1 (K), D4.1 (K), J2.1, J3.1, J3.2, R12.1, R14.1, R21.1, R22.2, R29.2, R30.2, R41.1, R42.1, R43.1, R44.1, R45.2, R46.2, R49.2, R50.2, R61.1, R62.1, R63.1, R64.1, R65.2, R66.2, TP1.1, TP3.1, TP4.1, TP6.1, U1.1 (DGND), U1.3 (VDRIVE), U1.6 (AGND), U1.14 (PGND), U1.17 (DGND), U1.19 (DGND), U1.25 (DGND), U1.34 (SELFBOOT), U1.36 (DGND), U1.37 (DGND), U1.54 (DGND), U1.55 (DGND), U1.72 (DGND), U1.73 (EP), U2.4 (Vss2), U2.19 (VSS1), U2.20 (VREFL), U2.33 (EP), U3.4 (Vss2), U3.19 (VSS1), U3.20 (VREFL), U3.33 (EP), U4.2 (GND), U5.1 (ADJ/GND), U6.1 (GND), U7.1, U8.1, U9.1, U10.1 (SHELL), U10.2 (SHELL), U10.3 (SHELL), U10.4 (SHELL), U10.A1B12 (GND), U10.B1A12 (GND), U11.1, U12.1, U13.1, U14.1, U15.1, U16.1, U17.1 (GND), U17.40 (GND), U17.41 (GND), U18.1, U19.1, U20.11 (VCC-), U21.11 (VCC-), U22.11 (VCC-), U23.11 (VCC-)
unnamed: C9.1, R1.2, X1.1
unnamed: C35.2, C38.2, R15.1
unnamed: C58.2, R31.1
unnamed: C59.2, R32.1
unnamed: C60.2, R35.1
unnamed: C61.2, R36.1
unnamed: C70.2, R53.1
unnamed: C71.2, R54.1
unnamed: C72.2, R55.1
unnamed: C73.2, R56.1
unnamed: D2.2 (A), R17.2
unnamed: D3.2 (A), R18.2
unnamed: D4.2 (A), R19.2
unnamed: J5.1, R25.1
unnamed: R15.2, R16.1
unnamed: C2.2, U2.5 (AVDRV)
unnamed: R3.2, U2.7 (BICK)
unnamed: R12.2, U2.27 (CAD/CSN)
unnamed: R2.2, U2.6 (LRCK)
unnamed: R4.2, U2.8 (MCLK)
unnamed: R8.2, U2.1 (SDIN1)
unnamed: R10.2, U2.31 (SDOUT1)
unnamed: C15.2, U2.17 (VCOM)
unnamed: C4.2, U3.5 (AVDRV)
unnamed: R6.2, U3.7 (BICK)
unnamed: R13.2, U3.27 (CAD/CSN)
unnamed: R5.2, U3.6 (LRCK)
unnamed: R7.2, U3.8 (MCLK)
unnamed: R9.2, U3.1 (SDIN1)
unnamed: R11.2, U3.31 (SDOUT1)
unnamed: C16.2, U3.17 (VCOM)
unnamed: C48.2, U6.3 (MR#), U7.2
unnamed: C53.2, U6.4 (VCC)
unnamed: R21.2, U10.A5 (CC1)
unnamed: R22.1, U10.B5 (CC2)
unnamed: R29.1, R33.1, U20.2 (IN1-)
unnamed: C62.1, R33.2, U20.1 (OUT1)
unnamed: R45.1, R47.1, U20.6 (IN2-)
unnamed: C68.1, R47.2, U20.7 (OUT2)
unnamed: R49.1, R51.1, U20.9 (IN3-)
unnamed: C74.1, R51.2, U20.8 (OUT3)
unnamed: R65.1, R67.1, U20.13 (IN4-)
unnamed: C80.1, R67.2, U20.14 (OUT4)
unnamed: R30.1, R34.1, U21.2 (IN1-)
unnamed: C63.1, R34.2, U21.1 (OUT1)
unnamed: R46.1, R48.1, U21.6 (IN2-)
unnamed: C69.1, R48.2, U21.7 (OUT2)
unnamed: R50.1, R52.1, U21.9 (IN3-)
unnamed: C75.1, R52.2, U21.8 (OUT3)
unnamed: R66.1, R68.1, U21.13 (IN4-)
unnamed: C81.1, R68.2, U21.14 (OUT4)
unnamed: R31.2, R37.2, R41.2, U22.3 (IN1+)
unnamed: C64.1, TP8.1, U22.1 (OUT1), U22.2 (IN1-)
unnamed: R32.2, R38.2, R42.2, U22.5 (IN2+)
unnamed: C65.1, TP9.1, U22.6 (IN2-), U22.7 (OUT2)
unnamed: R53.2, R57.2, R61.2, U22.10 (IN3+)
unnamed: C76.1, TP12.1, U22.8 (OUT3), U22.9 (IN3-)
unnamed: R54.2, R58.2, R62.2, U22.12 (IN4+)
unnamed: C77.1, TP13.1, U22.13 (IN4-), U22.14 (OUT4)
unnamed: R35.2, R39.2, R43.2, U23.3 (IN1+)
unnamed: C66.1, TP10.1, U23.1 (OUT1), U23.2 (IN1-)
unnamed: R36.2, R40.2, R44.2, U23.5 (IN2+)
unnamed: C67.1, TP11.1, U23.6 (IN2-), U23.7 (OUT2)
unnamed: R55.2, R59.2, R63.2, U23.10 (IN3+)
unnamed: C78.1, TP14.1, U23.8 (OUT3), U23.9 (IN3-)
unnamed: R56.2, R60.2, R64.2, U23.12 (IN4+)
unnamed: C79.1, TP15.1, U23.13 (IN4-), U23.14 (OUT4)

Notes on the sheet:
ESP32 & Local Control
ADAU1452
PDN Generator
ADAU1452 Power Nets
Analog Out
1.2V Generation
Audio Connectors
AMS1117-1.2
Heartbeats
AUX ESP32 Connections
AK4619
3.3V Source
ADAU1452 AUXADC/MP
ADAU1452 Clock Circuit
12V DC IN
Analog Input


Board: 4 copper layers, 100.0 x 80.0 mm, 199 parts (0 on the bottom side), 144 nets.

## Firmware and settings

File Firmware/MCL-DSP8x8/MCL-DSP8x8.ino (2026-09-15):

// MCL-DSP8x8 Firmware
// Author: Michael Larson
// Created: 3/20/2026
// Last modified: 5/13/2026
// Description: Firmware for ESP32-S3-WROOM-1U to control ADAU1452 and AK4619VN chips for an 8 channel in, 8 channel out DSP device.

// Note: uncomment below for simple ADAU1452 program
// #define ADAU1452_VERIFY

#include <Arduino.h>
#include <BLEDevice.h>
#include <BLEUtils.h>
#include <BLEServer.h>
#include <Wire.h>
#include <SPI.h>
#include "AK4619VN.h"
#include "ADAU1452.h"

// Heartbeat Constants and variables
#define HEARTBEAT_HALF_PERIOD_MS 1000
#define HEARTBEAT_LED 1
bool heartbeatState = HIGH;
int heartbeatTime = 0;

// BLE constants, variables, and objects
// https://www.uuidgenerator.net/
#define SERVICE_UUID "13ddec86-d2ca-4c9f-b360-20804ca3f1b4"
#define CHARACTERISTIC_UUID "13ddec86-d2ca-4c9f-b360-20804ca3f1b4"
BLEServer *pServer;
BLEService *pService;
BLEAdvertising *pAdvertising;
BLECharacteristic *gainCharacteristic;
// BLECharacteristic *


// Functions
void init_BLE();

void setup() {

  Serial.begin(115200);
  delay(1000);
  Serial.println("Serial begin success");

  // Initialize Heartbeat LED
  pinMode(HEARTBEAT_LED, OUTPUT);
  heartbeatTime = millis();

  // Initializing AK4619VN
  Serial.println("Programming AK4619VN");
  init_AK4619VN();
  Serial.println("Finished AK4619VN programming sequence");

  // mute during programming to prevent pop on output
  Serial.println("Muting output and programming ADAU1452");
  mute_AK4619VN();
  init_ADAU1452();
  unmute_AK4619VN();
  Serial.println("Finished ADAU1452 programming sequence... unmuting output");

  // Initializing BLE
  init_BLE();
}

void loop() {
  if (millis() > (heartbeatTime + HEARTBEAT_HALF_PERIOD_MS)) {
    heartbeatTime = millis();
    // digitalWrite(HEARTBEAT_LED, HIGH);
    digitalWrite(HEARTBEAT_LED, heartbeatState);

    heartbeatState = !heartbeatState;
// #ifdef ADAU1452_VERIFY
//     String temp_string = gainCharacteristic->getValue();
//     if(!temp_string.equals("X")) {
//       SIGMA_WRITE_REGISTER_FLOAT(MOD_MASTER_GAIN_ALG0_TARGET_ADDR, 0.125*(temp_string.toInt()));
//     }
// #endif
  }
}

void init_BLE() {
  if (!BLEDevice::init("MCL-DSP8x8")) {
    Serial.println("BLE initialization failed!");
    return;
  }

  pServer = BLEDevice::createServer();
  pService = pServer->createService(SERVICE_UUID);
  pServer->advertiseOnDisconnect(true);
  gainCharacteristic = pService->createCharacteristic(CHARACTERISTIC_UUID, BLECharacteristic::PROPERTY_READ | BLECharacteristic::PROPERTY_WRITE);

  gainCharacteristic->setValue("8");
  pService->start();

  pAdvertising = BLEDevice::getAdvertising();
  pAdvertising->addServiceUUID(SERVICE_UUID);
  pAdvertising->setScanResponse(true);
  pAdvertising->setMinPreferred(0x06);  // functions that help with iPhone connections issue
  pAdvertising->setMaxPreferred(0x12);
  BLEDevice::startAdvertising();
  Serial.println("BLE Started");
  return;
}

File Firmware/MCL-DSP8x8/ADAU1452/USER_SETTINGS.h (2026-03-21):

/*
 * File:			USER_SETTINGS.h
 *
 * Description:  	User-editable variables defining system behavior.
 *
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
 * This software may only be used to program products purchased from
 * Analog Devices for incorporation by you into audio products that
 * are intended for resale to audio product end users. This software
 * may not be distributed whole or in any part to third parties.
 *
 * Copyright � 2020 Analog Devices, Inc. All rights reserved.
 */

#ifndef __USER_SETTINGS_H__
#define __USER_SETTINGS_H__

#define DSP_TYPE_SIGMA100     1    // Sigma100: ADAU1701/ADAU1702/ADAU1401
#define DSP_TYPE_SIGMA200     2    // Sigma200: ADAU176x/ADAU178x/ADAU144x
#define DSP_TYPE_SIGMA300_350 3    // Sigma300/Sigma350: ADAU145x, ADAU146x

// Which type of DSP is connected?
#define DSP_TYPE DSP_TYPE_SIGMA300_350

/** If true, the DSP is programmed over SPI. If false, the DSP is programmed over I2C.
 * NOTE: On the example schematic I2C and SPI pins from the microcontroller are connected to
 * the same pins (because Sigma300/Sigma350 multiplex the I2C and SPI pins). The setup
 * function in main.cpp tristates the unused interface to avoid contention between I2C
 * and SPI pins.
 * NOTE: Sigma100 and Sigma200 place I2C on different USBi pins than Sigma300/Sigma350, again due
 * to pin multiplexing. This is why SDA and SCL will each appear twice on the USBi header in
 * the example schematic.
 */
#define USE_SPI true

#if USE_SPI
#include <SPI.h>
#endif

/** Set the SPI bus to run at a clock speed of 1MHz.
 * Very high SPI speeds (>15 MHz) may require shorter programmer cabling for sufficient signal
 * integrity. Keep the SPI speed low (~1MHz) the first time programming the DSP, once the code is
 * working try increasing the bus speed. SPI signal integrity should be verified on an oscilloscope. Some
 * SigmaDSPs have higher maximum SPI speeds than others. Check the datasheet of your DSP for the maximum
 * allowed SPI speed.
 */
#define SPI_SPEED 1000000
/**
 * Set the I2C bus to run at a clock speed of 400kHz (fast mode). I2C signal integrity
 * should be verified on an oscilloscope. Don't forget I2C pullup resistors!
 */
#define I2C_SPEED 400000


#if USE_SPI
const SPISettings settingsA(SPI_SPEED, MSBFIRST, SPI_MODE3);// Store SPI transaction information to settingsA
#endif

// Store mapping to USBi header here
#define DSP_RESET_PIN 9    // Any GPIO will work
#define DSP_SS_PIN    10

/** If SigmaStudio is set to use the DSP in SPI mode (default for Sigma300/Sigma350), the
 * SigmaStudio exported device address is 0x00. This causes issues if the microcontroller needs to
 * program the DSP over I2C. If OVERRIDE_SIGMASTUDIO_DEVICE_ADDRESS is true, SigmaStudioFW.cpp will
 * use the following device address instead of the one passed to it by argument. The Wire library
 * uses 7-bit I2C addressing, so the R/W bit is omitted from the device address.
 * NOTE: Manually overwriting DEVICE_ADDR_IC_1 in the SigmaStudio exported file is not a good idea
 * because the file will be re-created scratch every time a new SigmaStudio export is performed. It
 * is better to store this configuration data here. NOTE: Additional software logic will be needed
 * if more than one SigmaDSP IC is connected simultaneously.
 */
#define OVERRIDE_SIGMASTUDIO_DEVICE_ADDRESS true
#if OVERRIDE_SIGMASTUDIO_DEVICE_ADDRESS
#if DSP_TYPE == DSP_TYPE_SIGMA100
const int DSP_I2C_ADDR = 0b0110100;    // From ADAU1701 datasheet Table 15; assumes ADDR1 and ADDR0
                                       // low (eval board); adjust for your application.
#elif DSP_TYPE == DSP_TYPE_SIGMA200
const int DSP_I2C_ADDR = 0b0111000;    // From ADAU1761 datasheet Table 21; assumes ADDR1 and ADDR0
                                       // low (eval board); adjust for your application.
#elif DSP_TYPE == DSP_TYPE_SIGMA300_350
const int DSP_I2C_ADDR = 0b0111000;    // From ADAU1463 datasheet Table 26; assumes ADDR1 and ADDR0
                                       // low (eval board); adjust for your application.
#endif
#endif

#endif    // End of USER_SETTINGS.h

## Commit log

2026-03-14 v0.4 PCB - Partial Breakout
    This is the KiCad project for the first board that I ordered for testing
    [DIYDSPv0.4.csv, DIYDSPv0.4.kicad_pcb, DIYDSPv0.4.kicad_sch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]
2026-03-14 Delete DIYDSPv0.4 directory
    Figuring out Git
    [DIYDSPv0.4.csv, DIYDSPv0.4.kicad_pcb, DIYDSPv0.4.kicad_sch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]
2026-03-14 Added all PCB revisions
    [DIYDSP_BB_ADAU1452v0.1.csv, DIYDSP_BB_ADAU1452v0.1.kicad_pcb, DIYDSP_BB_ADAU1452v0.1.kicad_sch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]
2026-03-14 Started Arduino code/firmware
2026-03-21 Added Initial Firmware
    [DIYDSPv0.5.kicad_pcb, MCL-DSP8x8.params, freerouting.dsn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]
2026-03-25 Successful Programming of ESP32 and ADAU1452. Testing in progress for AK4619VN
    [ADAU1452_Heartbeat.params, MCL-DSP8x8.params]
2026-03-25 Specified I2C Speed
2026-04-01 Changes from testing first prototype (ADAU1452 Firmware is currently the Test firmware)
2026-04-29 PCB V0.6 for second prototype
    [DIYDSPv0.5.kicad_pcb, DIYDSPv0.5.kicad_sch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]
2026-04-29 Sent off for production
    [DIYDSPv0.6.kicad_pcb, bom.csv]
2026-05-12 New prototype design
    [DIYDSPv0.7.csv, DIYDSPv0.7.kicad_pcb, DIYDSPv0.7.kicad_sch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]
2026-05-13 Cleaned folders, cleaned firmware, v0.8 started.
    [DIYDSPv0.8.csv, DIYDSPv0.8.kicad_pcb, DIYDSPv0.8.kicad_sch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]
2026-05-31 Successful programming of v0.7 board
    [ADAU1452_Heartbeat.params, MCL-DSP8x8.params, MCL-DSP8x8Test.params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]
2026-07-04 Backing up progress (starting bluetooth, DSP project not in linear state).
    [DIYDSPv0.8.kicad_sch, MCL-DSP8x8.params, MCL-DSP8x8Test.params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]
2026-09-15 Updating progress on v0.8 design
    [DIYDSPv0.8.kicad_pcb, DIYDSPv0.8.kicad_sch, MCL-DSP8x8.params]
2026-09-18 v0.8 hardware schematic mostly complete
    [DIYDSPv0.8.kicad_sch]
2026-09-21 More progress on V0.8 layout. Still trying to figure out analog placement.
    [DIYDSPv0.8.kicad_pcb, DIYDSPv0.8.kicad_sch]
2026-09-25 Nearly done with v0.8 placement - Dealing with DRC errors
    [DIYDSPv0.8.kicad_pcb, DIYDSPv0.8.kicad_sch]
2026-09-25 V0.8 Complete. Will be working on audio connector boards.
    [DIYDSPv0.8.kicad_pcb, DIYDSPv0.8.kicad_sch, bom.csv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]
2026-09-25 Fix analog connector labels on v0.8 main board.
    [DIYDSPv0.8.kicad_pcb, MCL-DSP8x8_XLR_board.kicad_pcb, MCL-DSP8x8_XLR_board.kicad_sch]
2026-09-28 Added XLR Input board
    [MCL-DSP8x8_INPUT_XLR.kicad_pcb, MCL-DSP8x8_INPUT_XLR.kicad_sch, MCL-DSP8x8_XLR_board.kicad_pcb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]
2026-09-29 Added DC polarity indicator to main board, created RCA and XLR input/output
    [DIYDSPv0.8.kicad_pcb, MCL-DSP8x8_INPUT_RCA.kicad_pcb, MCL-DSP8x8_INPUT_RCA.kicad_sch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]
2026-09-29 Finished design of v1 connector boards.
    [MCL-DSP8x8_INPUT_RCA_8.kicad_pcb, MCL-DSP8x8_OUTPUT_RCA_8.kicad_pcb, MCL-DSP8x8_OUTPUT_RCA_8.kicad_sch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]
2026-10-11 Updated v0.8 PCB for final version and added version for external ESP32 dev board.
2026-10-18 Officially ordered v0.8 for validation - 12V input swapped for USB
2026-10-26 Ordered and updated schematic
2026-10-31 Update README.md
    Measured voltage input/output limits
